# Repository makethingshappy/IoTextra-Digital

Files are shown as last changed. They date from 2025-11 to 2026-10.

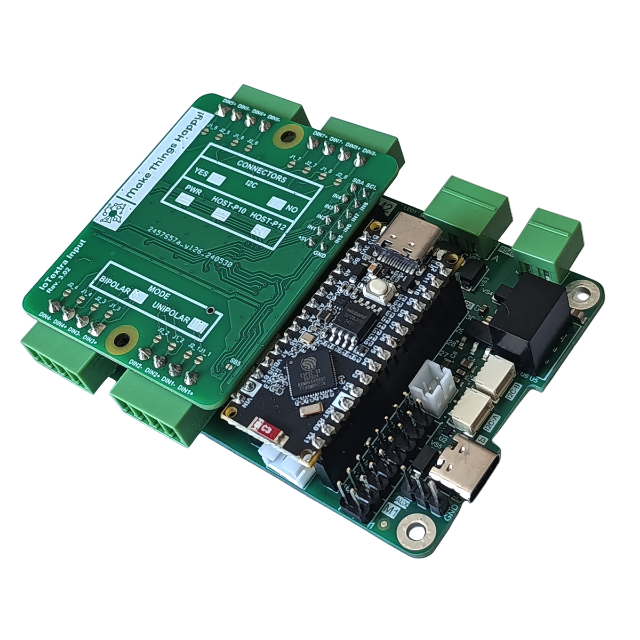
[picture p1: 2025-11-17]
Input/v.3.02/media/14_-_IoTbase_NANO_and_IoTextra_Input_with_ESP32-S3-Nano_Development_Board.png

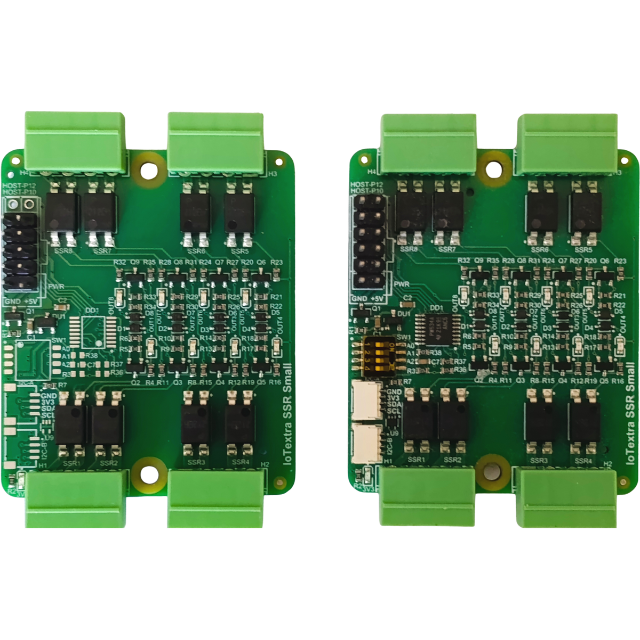
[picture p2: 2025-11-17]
SSR Small/v.3.02/media/02_-_IoTextra_SSR_Small_with_and_without_Qwiic_connector.png

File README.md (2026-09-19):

# IoTextra-Digital: Industrial Digital I/O Modules for MQTT & Node-RED Automation

## Overview

[**IoTextra-Digital**](https://makethingshappy.io/collections/digital-iotextra) is a family of isolated digital I/O modules designed for reliable operation in IoT, IIoT, and smart home environments.  
Each module combines digital inputs with relay, solid-state relay, transistor, or MOSFET outputs — the exact configuration, voltage range, and isolation technology vary by module and are documented in its own datasheet.

IoTextra modules integrate cleanly with IoTsmart MCU boards and can be used with MQTT and Node-RED workflows (e.g., via the IoTflow automation framework).

---

## Features & Capabilities

- Industrial-grade digital I/O, galvanically isolated per channel
- Relay, solid-state relay, transistor, or MOSFET outputs depending on the module
- Clean terminal block layout for fast, error-free wiring
- Compatible with IoTsmart modules, Raspberry Pi PICO, and other MCUs
- Suitable for long-term installations in smart buildings, labs, and light industrial systems

---

## Hardware Specifications

Each IoTextra-Digital module has its own electrical and mechanical specifications, documented inside its versioned folder.

Module folders:

- **[Input](./Input/)**
- **[MOSFET2](./MOSFET2/)**
- **[Octal](./Octal/)**
- **[Octal2](./Octal2/)**
- **[Octal3](./Octal3/)**
- **[Octal4](./Octal4/)**
- **[Relay](./Relay/)**
- **[Relay2](./Relay2/)**
- **[SSR Small](./SSR%20Small/)**

Typical documentation includes:

- Maximum input voltage and isolation rating (varies by module — see individual datasheet)
- Output type and ratings (relay, SSR, transistor, or MOSFET)
- Electrical thresholds and isolation design
- Load and protection characteristics
- Mechanical layout and terminal labeling

Refer to each module's documentation for exact technical data.

---

## Digital I/O Channel Configuration

Documentation includes:

- Input and output channel numbering
- Terminal block identification
- Wiring patterns for switches, sensors, and loads
- Recommended safety and polarity guidelines

> **Important:**  
> Output type differs by module — NPN transistor outputs (Octal2), MOSFET outputs (MOSFET2), and relay or solid-state relay outputs (all other modules). Check the specific module's datasheet before wiring.

---

## Wiring & Pinout Diagrams

Module-level wiring diagrams include:

- Terminal block layout  
- Polarity and signal direction  
- Relay/SSR/transistor/MOSFET load wiring examples  
- Safety considerations for higher-voltage operation  

See the diagrams located in each module's folder listed above.

---

## Software Support

IoTextra-Digital is a **hardware-only** series, but integrates cleanly into automation stacks.

Typical usage includes:

- Connecting module inputs/outputs to IoTsmart or Raspberry Pi PICO boards  
- Reading/writing digital I/O via GPIO or MCU firmware  
- Triggering MQTT events or Node-RED flows  
- Following IoTflow's MQTT topic conventions for automation

---

## Examples

IoTextra-Digital modules are used together with [**IoTsmart**](https://makethingshappy.io/collections/iotsmart) or [**IoTbase**](https://makethingshappy.io/collections/iotbase) boards and [**IoTflow-based**](https://makethingshappy.io/pages/iotflow) automation.

Module-specific diagrams and connection examples are included inside each module's folder listed above.

### MCU Firmware Examples (IoTsmart)

IoTsmart does **not** yet contain its own `/examples` folder.  
Firmware reference examples will be added in a future update.

### Node-RED Automation Examples (IoTflow)

👉 **IoTflow Node-RED Examples**  
https://github.com/makethingshappy/IoTflow/tree/main/Node-RED%20Examples

---

## Ordering Information

### 📦 SKU Information  
The complete list of SKUs is provided in the following PDF located in the repository root:

- **SKU Digital IoTextra.pdf**

---

### 🛒 Purchase Links  
Order directly from the official store:

* [**IoTextra Input Module**](https://makethingshappy.io/collections/digital-iotextra/products/iotextra-input)
* [**IoTextra MOSFET2 Module**](https://makethingshappy.io/collections/digital-iotextra/products/iotextra-mosfet2)
* [**IoTextra Octal Module**](https://makethingshappy.io/collections/digital-iotextra/products/iotextra-octal)
* [**IoTextra Octal2 Module**](https://makethingshappy.io/collections/digital-iotextra/products/iotextra-octal2)
* [**IoTextra Octal3 Module**](https://makethingshappy.io/collections/digital-iotextra/products/iotextra-octal3)
* [**IoTextra Octal4 Module**](https://makethingshappy.io/collections/digital-iotextra/products/iotextra-octal4)
* [**IoTextra Relay2 Module**](https://makethingshappy.io/collections/digital-iotextra/products/iotextra-relay2)
* [**IoTextra SSR Small Module**](https://makethingshappy.io/collections/digital-iotextra/products/iotextra-ssr-small)

---

## Licensing

This repository uses separate licenses for each category of assets:

- **Code:** [`LICENSE_CODE.md`](./LICENSE_CODE.md) — MIT License  
- **Schematics & Documentation:** [`LICENSE_HARDWARE.md`](./LICENSE_HARDWARE.md) — CC BY-SA 4.0  
- **Documentation:** [`LICENSE_DOCS.md`](./LICENSE_DOCS.md)  
- **Media:** [`LICENSE_MEDIA.md`](./LICENSE_MEDIA.md)

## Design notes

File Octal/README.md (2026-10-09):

<!-- OVERVIEW_START -->
> **IoTextra Octal**
>
> 4+2+2 I/O module · 4 digital inputs · 2 NPN outputs · 2 SPST relays · galvanic isolation · 3750 VRMS
>
> Inputs up to 36 VDC · outputs up to 100 VDC / 8 A · relay 250 VAC / 5 A · HOST and Qwiic connectors
>
> Works with Raspberry Pi, Raspberry Pi Pico / Pico 2 (RP2040 / RP2350) and ESP32
>
> DIN-rail mounting: A 3D-printable DIN-rail mounting tray is available — <a href="https://www.printables.com/model/1802141-din-rail-mount-for-make-things-happy-iotextra">view on Printables</a>
>
> Part of the IoTextra series · compatible with IoTsmart and IoTbase · Open Hardware
<!-- OVERVIEW_END -->

software

## SKU

See [SKU.md](SKU.md)

## Version history

| Version | Notes |
|---|---|
| 3.04 | QR code and logos added to bottom side |
| 3.03 | Initial GitHub release |

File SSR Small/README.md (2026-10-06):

<!-- OVERVIEW_START -->
> **IoTextra SSR Small**
>
> 8-channel solid-state relay module · SPST-NO · galvanic isolation · 5000 VRMS · on-resistance from 0.05 Ω
>
> GPIO and/or I²C modes · HOST and Qwiic connectors · 47×56 mm · 5 VDC supply
>
> Works with Raspberry Pi, Raspberry Pi Pico / Pico 2 (RP2040 / RP2350) and ESP32
>
> DIN-rail mounting: A 3D-printable DIN-rail mounting tray is available — <a href="https://www.printables.com/model/1802141-din-rail-mount-for-make-things-happy-iotextra">view on Printables</a>
>
> Part of the IoTextra series · compatible with IoTsmart and IoTbase · Open Hardware
<!-- OVERVIEW_END -->

software

## SKU

See [SKU.md](SKU.md)

## Version history

| Version | Notes |
|---|---|
| 3.02 | Initial GitHub release |

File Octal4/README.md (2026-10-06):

<!-- OVERVIEW_START -->
> **IoTextra Octal4**
>
> 4 isolated digital inputs · 4 SPST relays · galvanic isolation · 2500 VRMS
>
> Inputs field-configurable 12/18/24/36 VDC per channel via solder jumpers · relay contacts 250 VAC / 30 VDC / 5 A · control via GPIO and/or I²C (TCA9534)
>
> Works with Raspberry Pi, Raspberry Pi Pico / Pico 2 (RP2040 / RP2350) and ESP32
>
> DIN-rail mounting: A 3D-printable DIN-rail mounting tray is available — <a href="https://www.printables.com/model/1802141-din-rail-mount-for-make-things-happy-iotextra">view on Printables</a>
>
> Part of the IoTextra series · compatible with IoTsmart and IoTbase · Open Hardware
<!-- OVERVIEW_END -->

software

## SKU

See [SKU.md](SKU.md)

## Version history

| Version | Notes |
|---|---|
| 3.02 | Initial GitHub release |

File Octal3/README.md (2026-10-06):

<!-- OVERVIEW_START -->
> **IoTextra Octal3**
>
> 4 isolated digital inputs · 4 latching DPDT relays · galvanic isolation · 3750 VRMS
>
> Inputs up to 36 VDC via GPIO · relay contacts 250 VAC / 220 VDC / 2 A · relay control via I²C → TCA9534A → DRV8837C
>
> Works with Raspberry Pi, Raspberry Pi Pico / Pico 2 (RP2040 / RP2350) and ESP32
>
> DIN-rail mounting: A 3D-printable DIN-rail mounting tray is available — <a href="https://www.printables.com/model/1802141-din-rail-mount-for-make-things-happy-iotextra">view on Printables</a>
>
> Part of the IoTextra series · compatible with IoTsmart and IoTbase · Open Hardware
<!-- OVERVIEW_END -->

software

latching

## SKU

See [SKU.md](SKU.md)

## Version history

| Version | Notes |
|---|---|
| 3.02 | Initial GitHub release |

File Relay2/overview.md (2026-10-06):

# IoTextra Relay2

4-channel SPDT relay module · 250 VAC / 30 VDC · 10 A · GPIO and/or I²C modes

Relay options: Panasonic ALQ105 · Omron G5Q-14 · HF33F/005-ZS3 · TE PE014005 · HOST and Qwiic connectors

Works with Raspberry Pi, Raspberry Pi Pico / Pico 2 (RP2040 / RP2350) and ESP32

DIN-rail mounting: A 3D-printable DIN-rail mounting tray is available — <a href="https://www.printables.com/model/1802141-din-rail-mount-for-make-things-happy-iotextra">view on Printables</a>

Part of the IoTextra series · compatible with IoTsmart and IoTbase · Open Hardware

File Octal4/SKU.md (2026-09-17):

# SKU — IoTextra Octal4

```
040305vvvrcc
```

| Field | Description |
|---|---|
| `040305` | Product code — IoTextra Octal4 |
| `vvv` | Version (e.g. 302 = version 3.02) |
| `r` | Relay model |
| `cc` | Communication |

**Relay model (r):**

| Value | Description |
|---|---|
| 1 | HF49FD |
| 2 | APAN3105 |

**Communication (cc):**

| Value | Description |
|---|---|
| 11 | HOST-12 connector and two I²C connectors |

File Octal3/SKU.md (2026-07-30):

# SKU — IoTextra Octal3

```
040304vvvrcc
```

| Field | Description |
|---|---|
| `040304` | Product code — IoTextra Octal3 |
| `vvv` | Version (e.g. 302 = version 3.02) |
| `r` | Relay model |
| `cc` | Communication |

**Relay model (r):**

| Value | Description |
|---|---|
| 3 | KEMET EC2-5SNU |

**Communication (cc):**

| Value | Description |
|---|---|
| 09 | HOST-12 connector |
| 11 | HOST-12 connector and two I²C connectors |

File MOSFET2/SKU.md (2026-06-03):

# SKU — IoTextra MOSFET2

```
040206vvvmpc
```

| Field | Description |
|---|---|
| `040206` | Product code — IoTextra MOSFET2 |
| `vvv` | Version (e.g. 302 = version 3.02) |
| `m` | MOSFET variant (load voltage / load current) |
| `p` | DC-DC converter |
| `c` | Communication |

**MOSFET variant (m):**

| Value | Description |
|---|---|
| 1 | 30 VDC / 9 A |
| 2 | 60 VDC / 7 A |
| 3 | 90 VDC / 6 A |

**DC-DC converter (p):**

| Value | Description |
|---|---|
| 1 | 5V→5V |
| 2 | 5V→5V tall |
| 3 | 2× (5V→5V tall) |
| 4 | 5V→12V tall |

**Communication (c):**

| Value | Description |
|---|---|
| A | HOST-10 connector |
| 9 | HOST-12 connector |
| B | HOST-12 connector and two I²C connectors |

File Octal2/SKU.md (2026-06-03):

# SKU — IoTextra Octal2

```
040303vvvscc
```

| Field | Description |
|---|---|
| `040303` | Product code — IoTextra Octal2 |
| `vvv` | Version (e.g. 302 = version 3.02) |
| `s` | Signal type |
| `cc` | Communication |

**Signal type (s):**

| Value | Description |
|---|---|
| 2 | Bipolar |
| 3 | Extended |

**Communication (cc):**

| Value | Description |
|---|---|
| 10 | HOST-10 connector |
| 09 | HOST-12 connector |
| 11 | HOST-12 connector and two I²C connectors |

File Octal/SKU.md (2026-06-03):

# SKU — IoTextra Octal

```
040302vvvrcc
```

| Field | Description |
|---|---|
| `040302` | Product code — IoTextra Octal |
| `vvv` | Version (e.g. 304 = version 3.04) |
| `r` | Relay model |
| `cc` | Communication |

**Relay model (r):**

| Value | Description |
|---|---|
| 1 | HF49FD |
| 2 | APAN3105 |

**Communication (cc):**

| Value | Description |
|---|---|
| 10 | HOST-10 connector |
| 11 | HOST-12 connector and two I²C connectors |

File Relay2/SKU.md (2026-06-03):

# SKU — IoTextra Relay2

```
040202vvvrcc
```

| Field | Description |
|---|---|
| `040202` | Product code — IoTextra Relay2 |
| `vvv` | Version (e.g. 302 = version 3.02) |
| `r` | Relay model |
| `cc` | Communication |

**Relay model (r):**

| Value | Description |
|---|---|
| 1 | HF33F/005-ZS3 |
| 2 | Panasonic ALQ105 |
| 3 | Omron G5Q-14 |
| 4 | TE PE014005 |

**Communication (cc):**

| Value | Description |
|---|---|
| 10 | HOST-10 connector |
| 11 | HOST-12 connector and two I²C connectors |

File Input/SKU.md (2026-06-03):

# SKU — IoTextra Input

```
040101vvvscc
```

| Field | Description |
|---|---|
| `040101` | Product code — IoTextra Input |
| `vvv` | Version (e.g. 302 = version 3.02) |
| `s` | Signal type |
| `cc` | Communication |

**Signal type (s):**

| Value | Description |
|---|---|
| 0 | Unipolar |
| 1 | Bipolar |

**Communication (cc):**

| Value | Description |
|---|---|
| 10 | HOST-10 connector |
| 09 | HOST-12 connector |
| 11 | HOST-12 connector and two I²C connectors |

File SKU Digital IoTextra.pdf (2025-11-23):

## SKU - Digital IoTextra

IoTextra Input
040101vvvscc
vvv | - | Version (for example, 302 is version 3.02)
s | - | Signal type (0 – Unipolar, 1 – Bipolar)
сс | - | Communication:
| | 10 –HOST-10 connector
| | 02 – PWR connector and two I²C connectors
| | 09 – HOST-12 connector
| | 11– HOST-12 connector and two I2C connectors

IoTextra Relay2
040202vvvrcc
vvv | - | Version (for example, 302 is version 3.02)
r | - | Relay model:
| | 1 – 33F/005
| | 2 – ALQ105
| | 3 – G5Q-14
| | 4 – PE014005
сс | - | Communication:
| | 10 –HOST-10 connector
| | 02 – PWR connector and two I²C connectors
| | 11– HOST-12 connector and two I2C connectors

IoTextra SSR Small
040203vvvlcc
vvv | - | Version (for example, 302 is version 3.02)
l | - | Load voltage / Load current:
| | 1 – 350VAC / 0.12A
| | 2 – 60VDC / 0.5A
| | 3 – 40VDC / 2A
| | 4 – 30VDC / 4A
сс | - | Communication:
| | 10 –HOST-10 connector
| | 02 – PWR connector and two I²C connectors
| | 09 – HOST-12 connector
| | 11– HOST-12 connector and two I2C connectors

IoTextra Octal2
040101vvvscc
vvv | - | Version (for example, 302 is version 3.02)
s | - | Signal type (1 – Unipolar, 2 – Bipolar, 3 – Extended)
сс | - | Communica:
| | 10 –HOST-10 connector
| | 02 – PWR connector and two I²C connectors
| | 09 – HOST-12 connector
| | 11– HOST-12 connector and two I2C connectors

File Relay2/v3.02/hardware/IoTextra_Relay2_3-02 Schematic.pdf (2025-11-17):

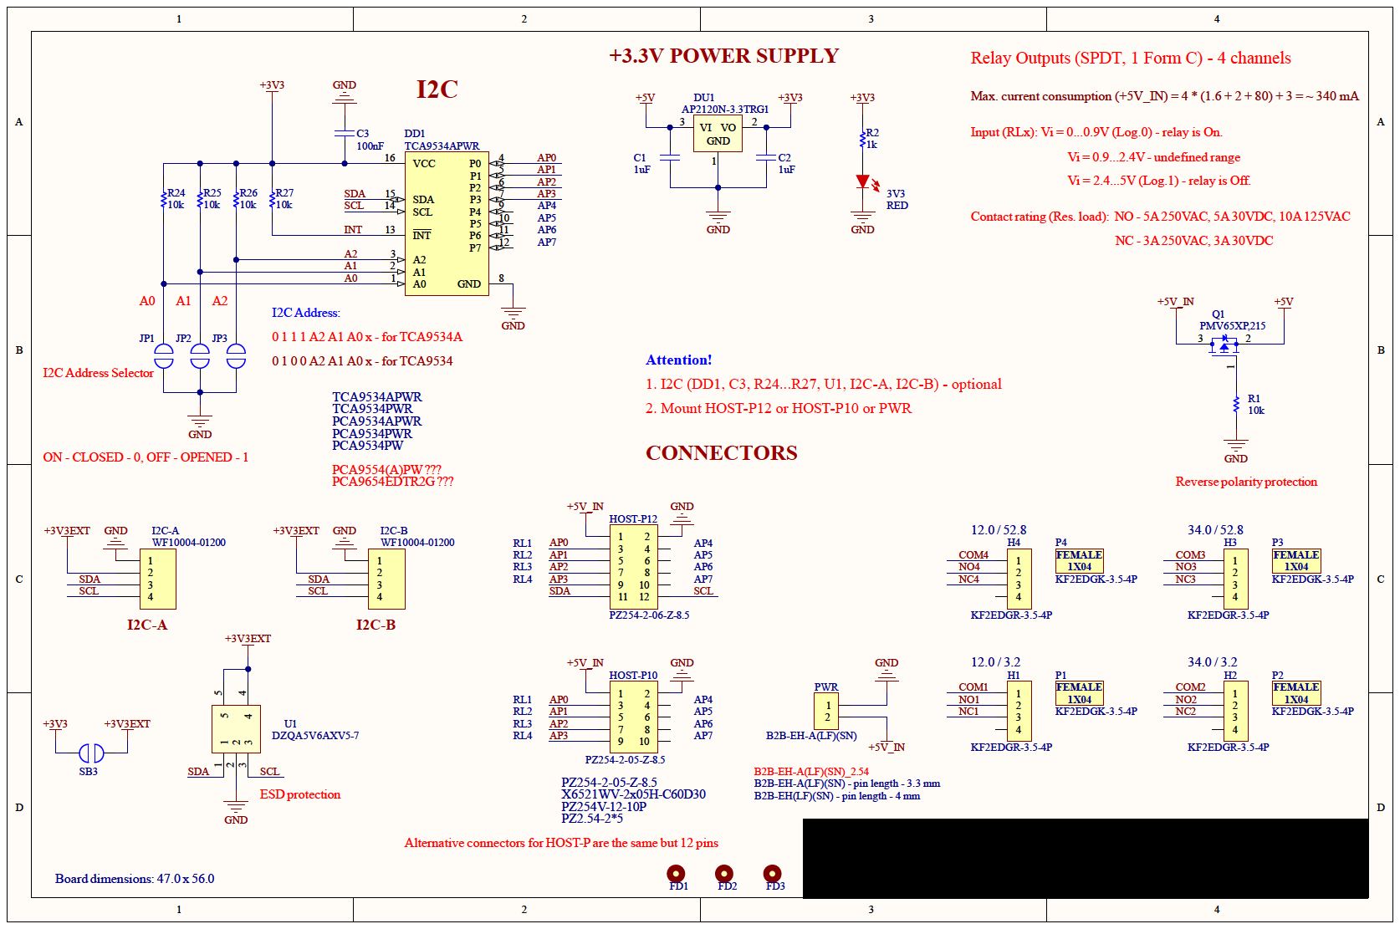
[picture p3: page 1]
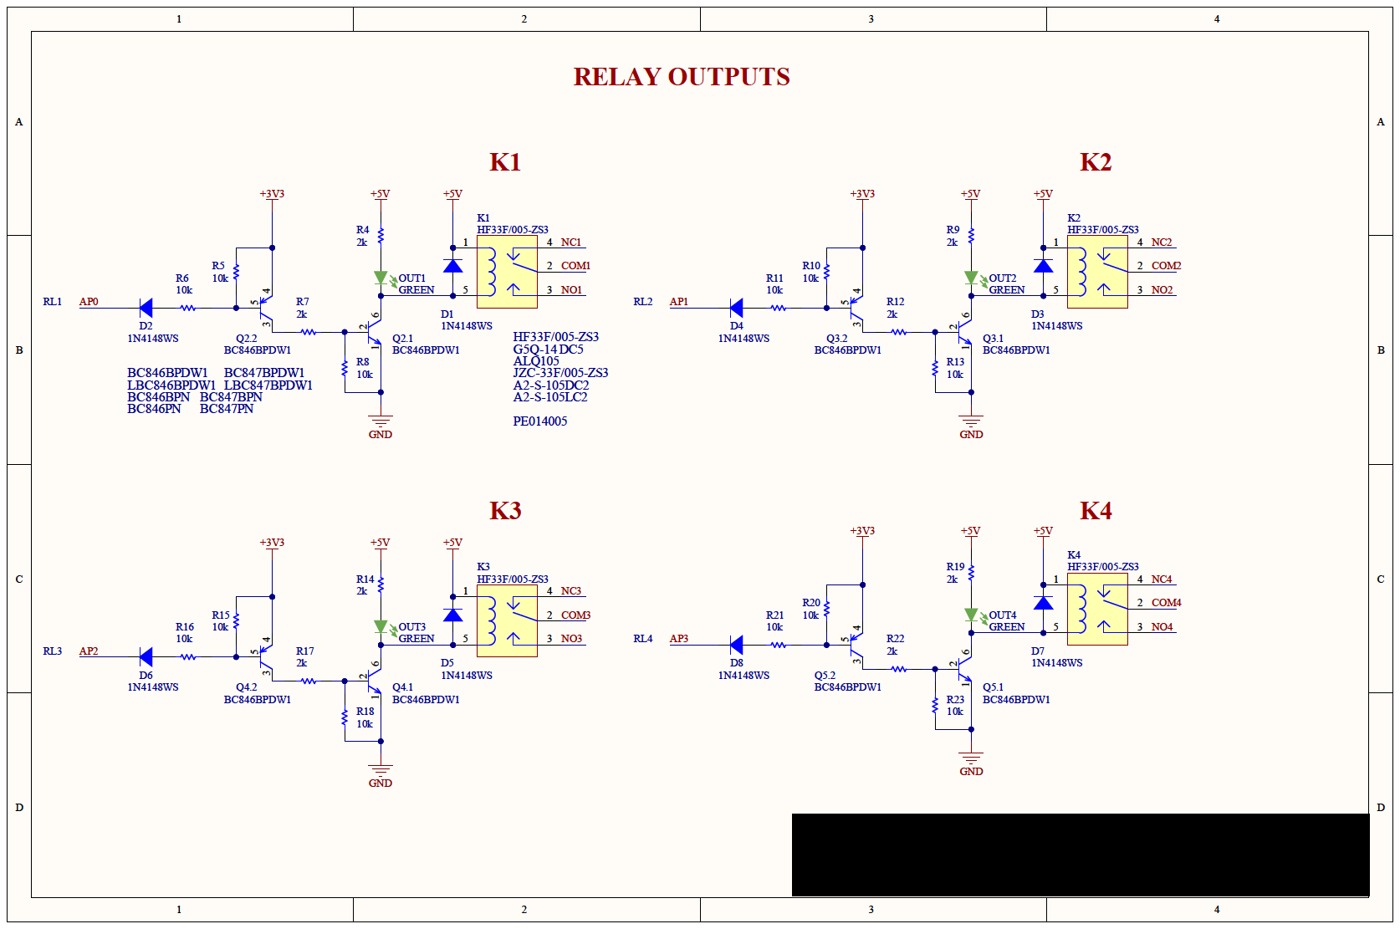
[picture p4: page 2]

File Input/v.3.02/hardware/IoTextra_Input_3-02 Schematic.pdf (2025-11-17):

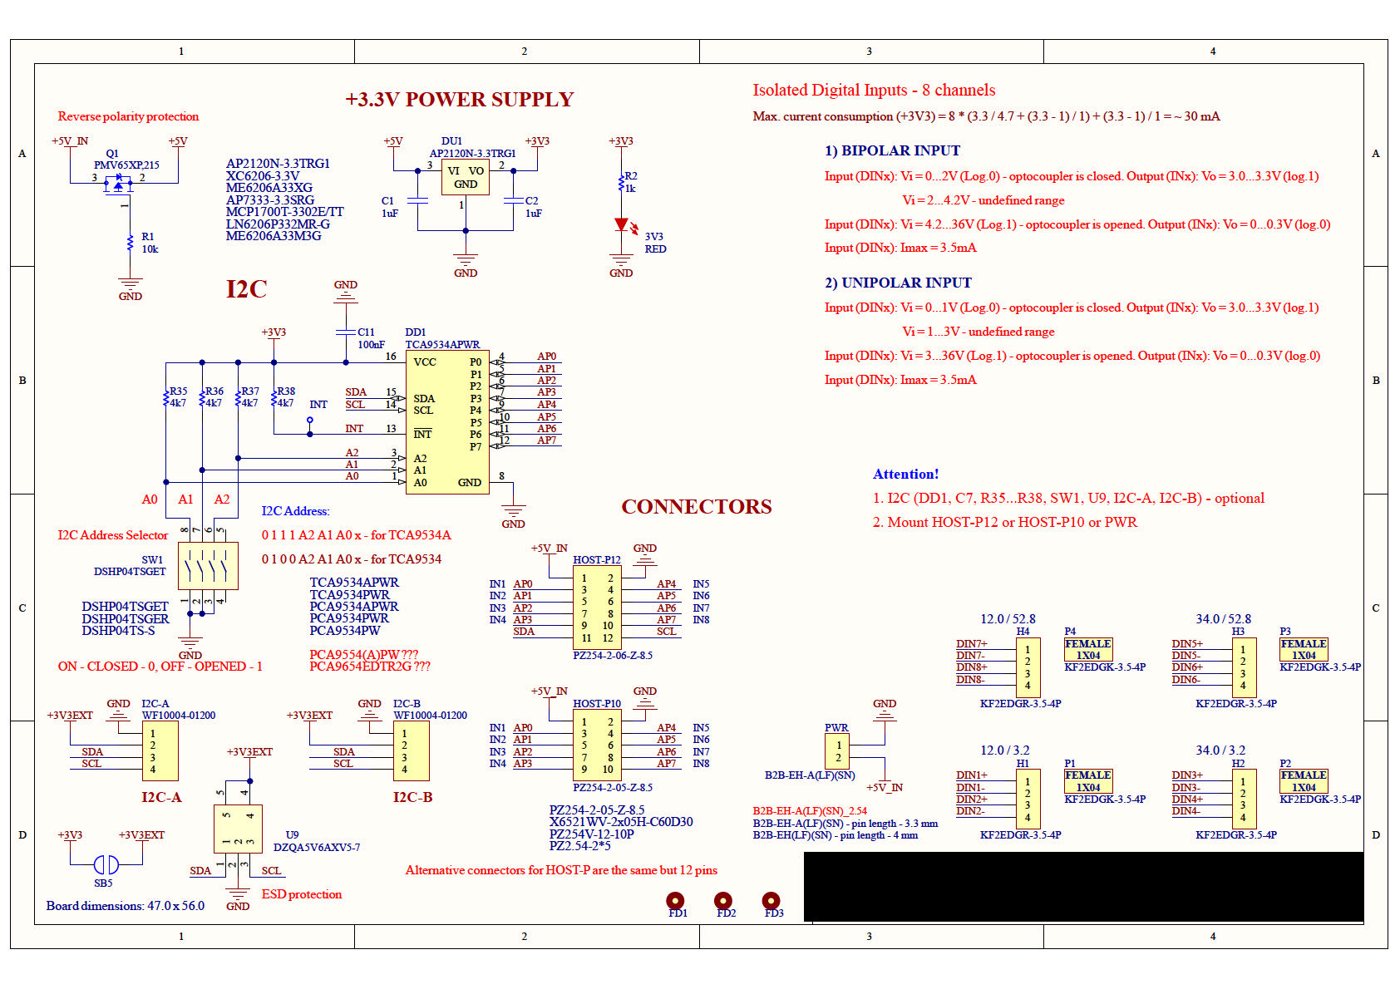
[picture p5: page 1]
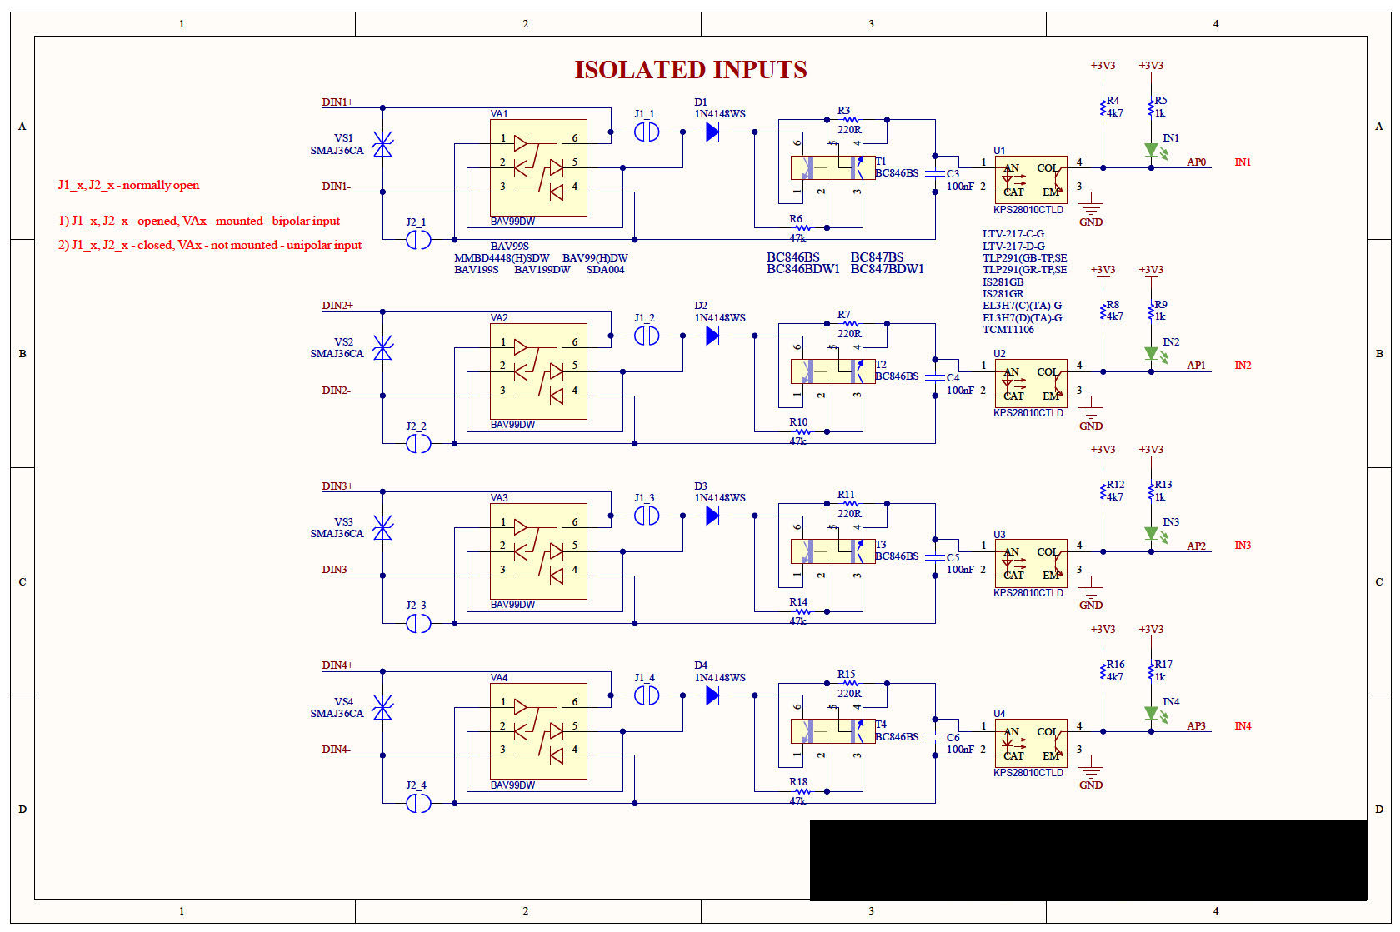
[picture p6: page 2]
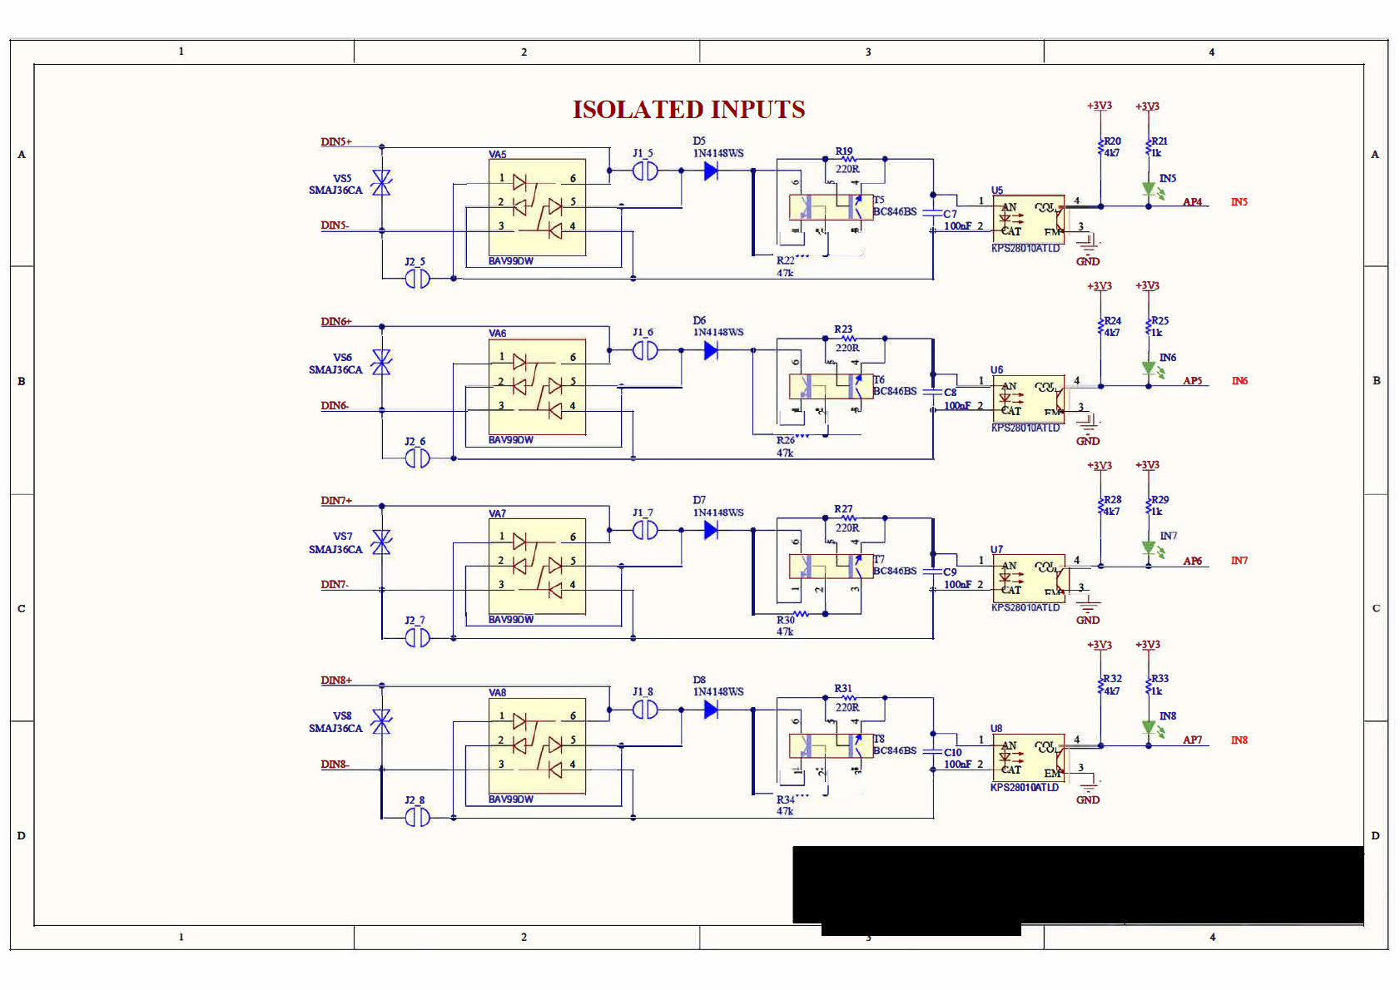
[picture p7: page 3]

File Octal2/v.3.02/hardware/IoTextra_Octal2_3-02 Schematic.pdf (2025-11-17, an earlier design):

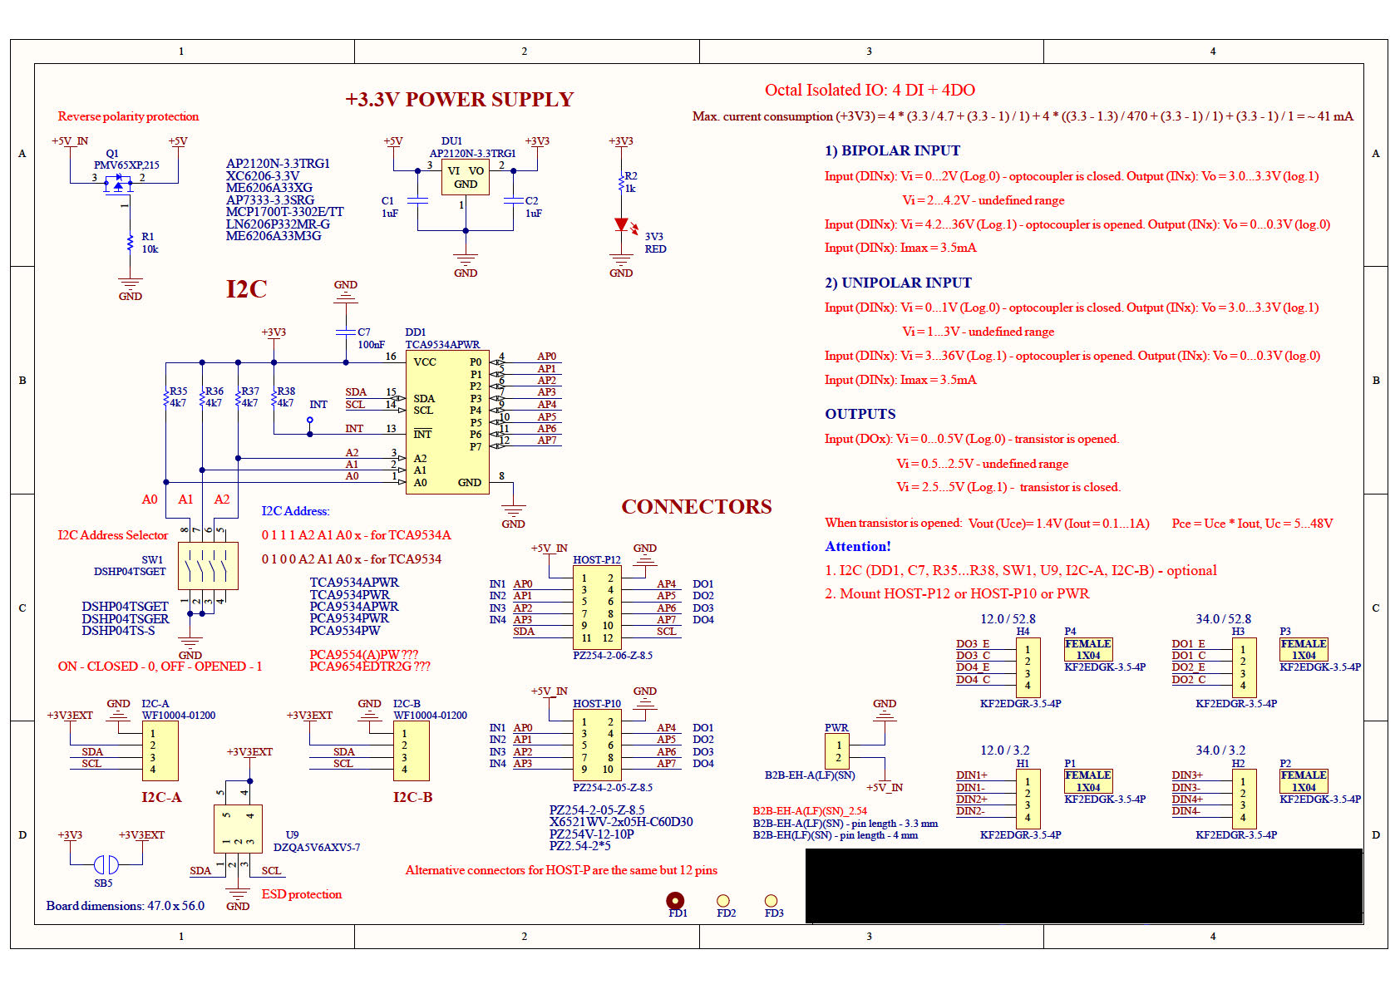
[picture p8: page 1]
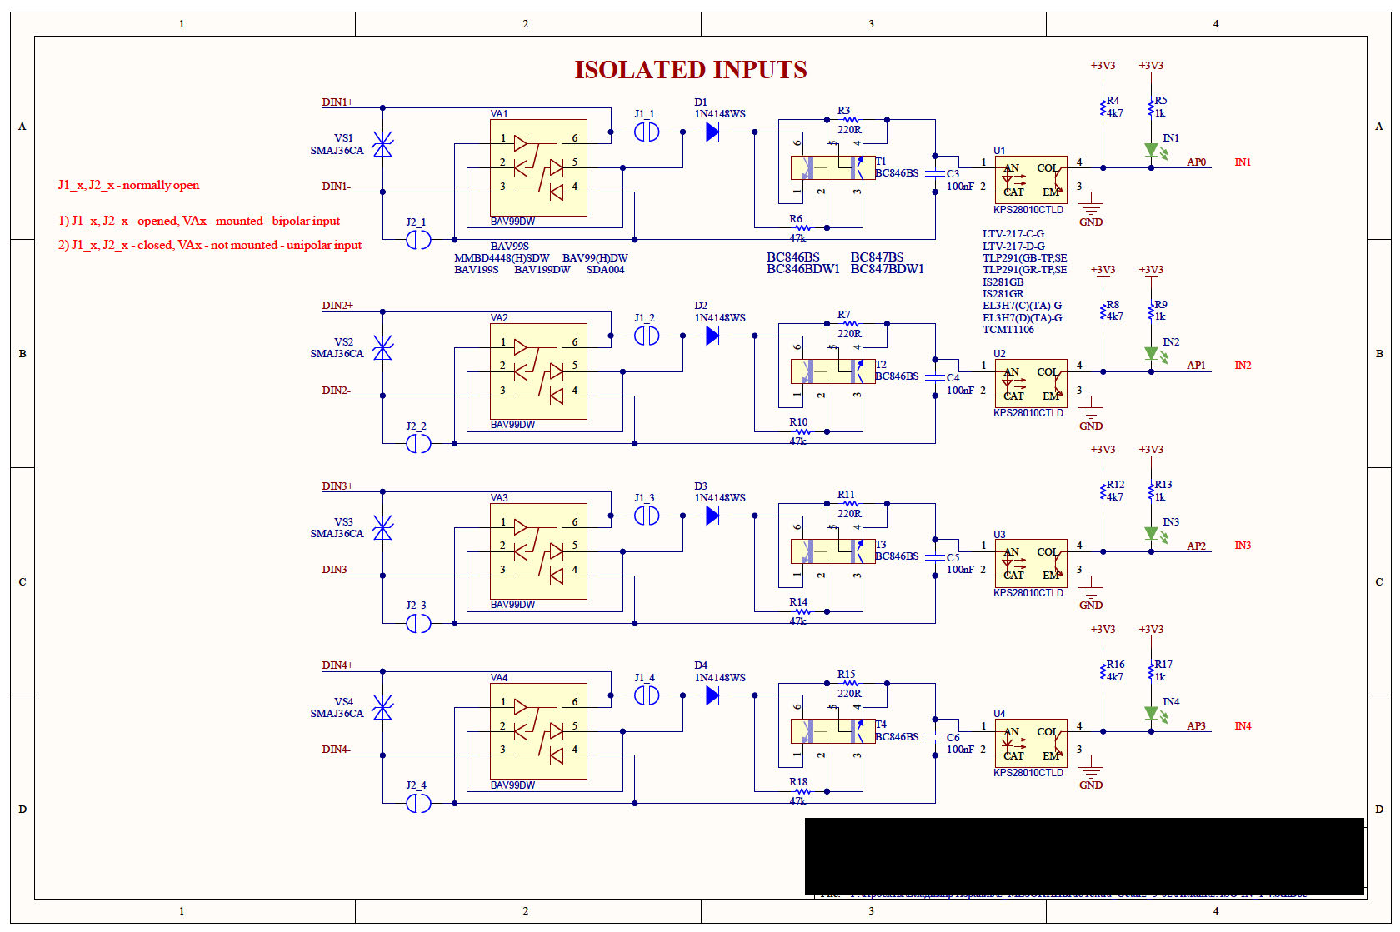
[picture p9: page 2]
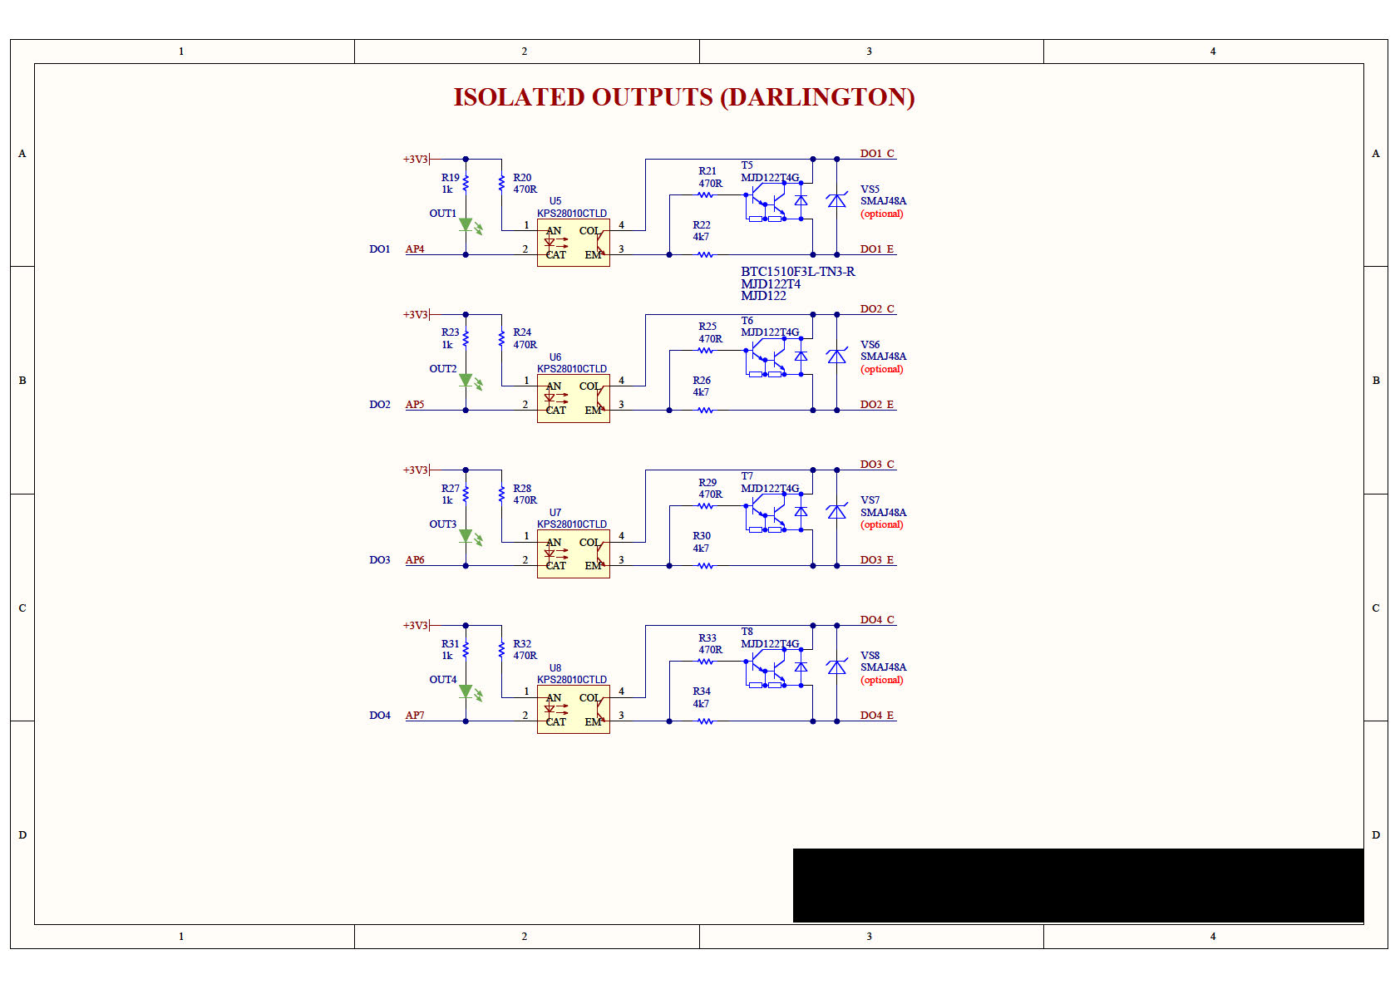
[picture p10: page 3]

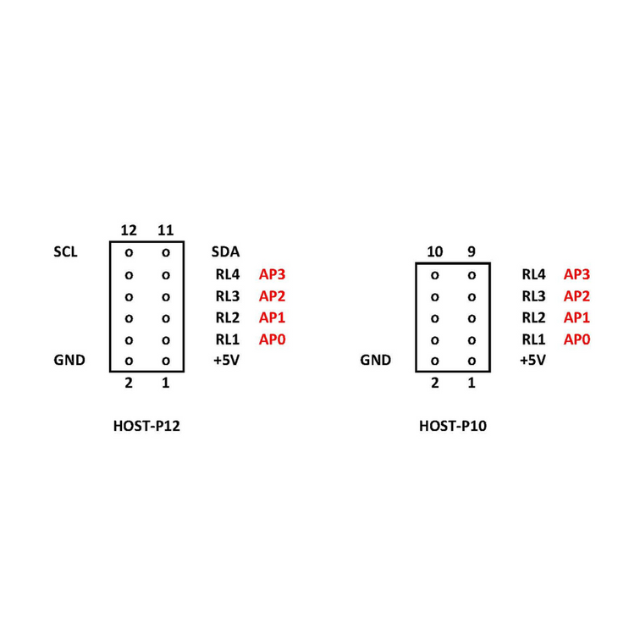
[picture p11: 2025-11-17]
Relay2/v3.02/media/05_-_IoTextra_Relay2_HOST_connector_pinout.png

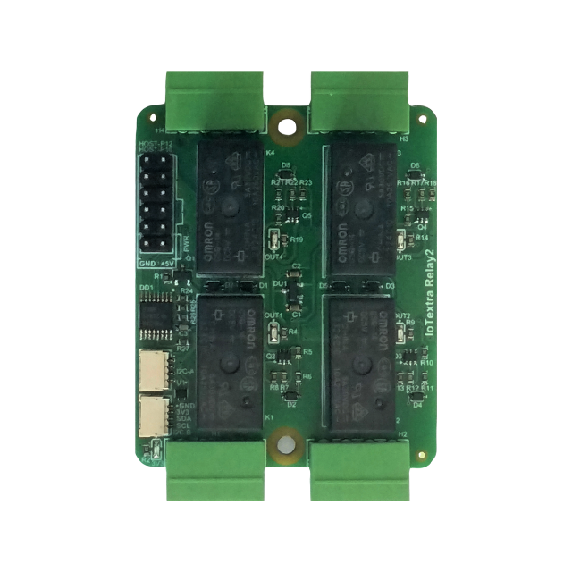
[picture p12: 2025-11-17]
Relay2/v3.02/media/03_-_IoTextra_Relay2_TOP_view.png

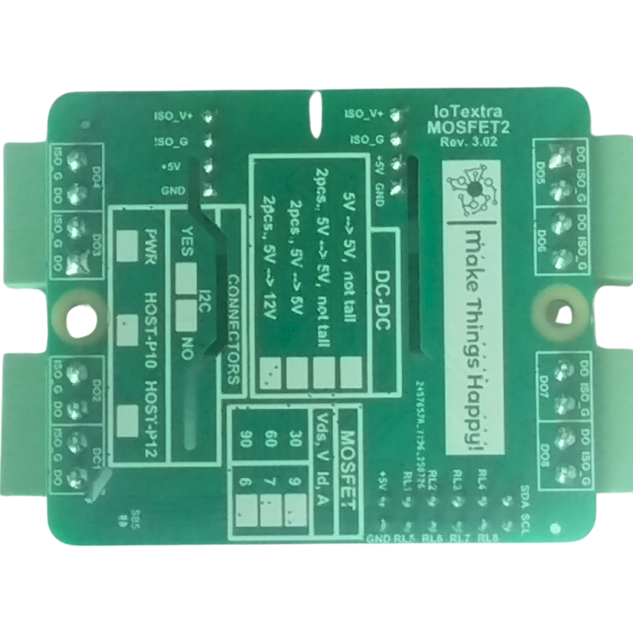
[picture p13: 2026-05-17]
MOSFET2/v.3.02/media/03 - IoTextra MOSFET2 BOTTOM view.png

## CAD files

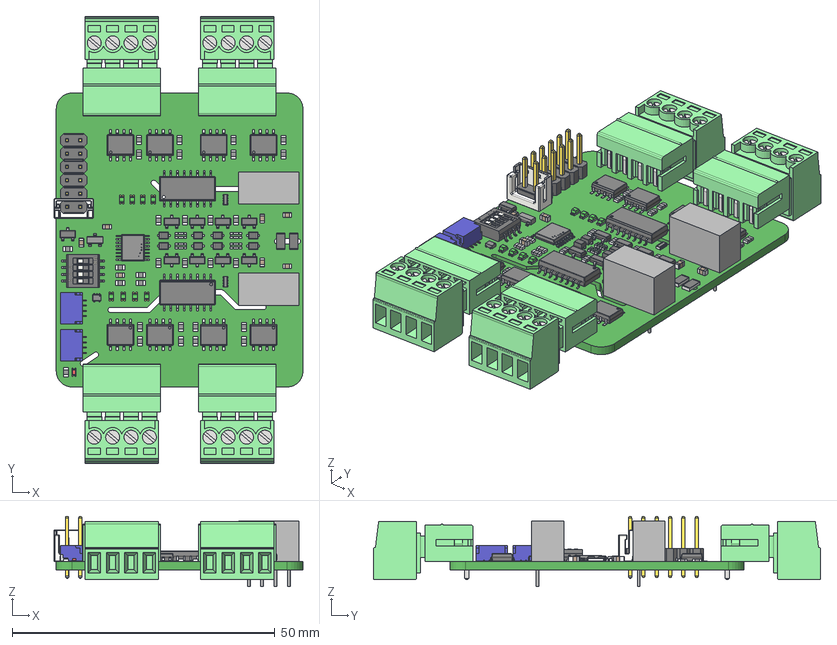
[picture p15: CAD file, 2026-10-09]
MOSFET2/v.3.02/hardware/IoTextra MOSFET2 ver.3-02.step
47.4 x 85.2 x 13.4 mm
Resistor_Array_YC_AF_xxx_YC124-FR-0759RL x 2
EXB28V_PAN x 4
NZQA5V6XV5T1G
Mid Body x 2
Mark x 2
CRE1_3C_MUR_RGB8421504 x 2
RESC1608X50N x 30
Leader x 123
CAPC1608X100N x 7
Lens x 8
User Library-SOD323F-1 x 8
PLD-12
B2B-EH-A
JST Logo adjustable
SMT_switch_04
BODY-TSSOP
LEAD-TSSOP x 16
Texas Logo Yury
Texas Logo Yury - Copy
SM04B-SRSS-TB x 2
PLD-10
ECH350R-04P x 4
EC350V-04P x 4
SOT95P240X110-3N

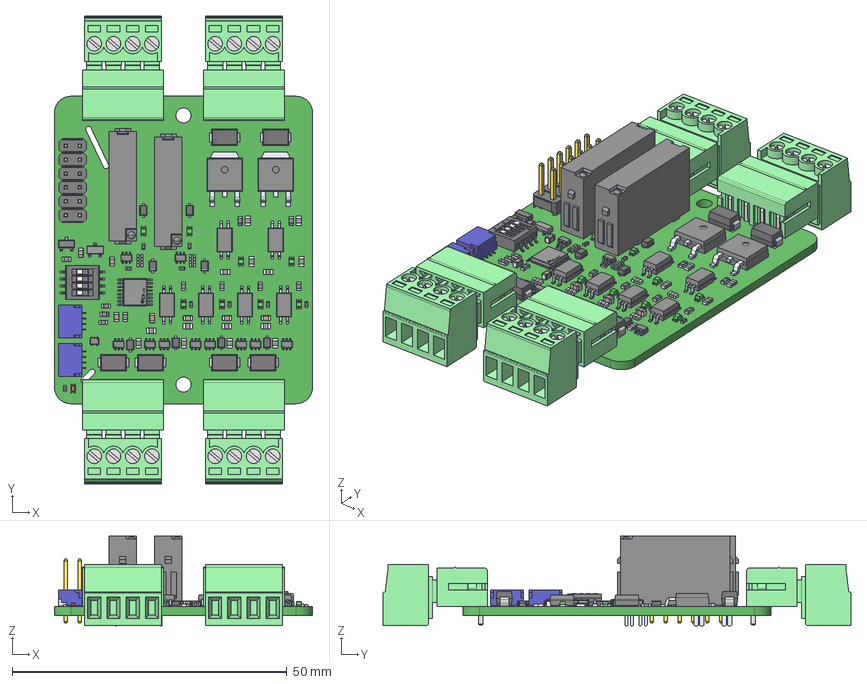
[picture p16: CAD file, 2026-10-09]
Octal/v.3.04/hardware/IoTextra Octal 3-04.step
47.0 x 85.2 x 16.3 mm
TCMD1000--3DModel-STEP-56544 x 6
User Library-S1G-1 x 6
RESC1608X50N x 14
Lens x 8
Mid Body x 9
Mark x 9
User Library-SOD323F-1 x 8
PLD-12
NZQA5V6XV5T1G
Leader x 3
SMT_switch_04
CAPC1608X100N x 7
BODY-TSSOP
LEAD-TSSOP x 16
Texas Logo Yury
Texas Logo Yury - Copy
SM04B-SRSS-TB x 2
PLD-10
ECH350R-04P x 4
EC350V-04P x 4
SOT95P240X110-3N
Extruded x 4
EXB28V_PAN x 2

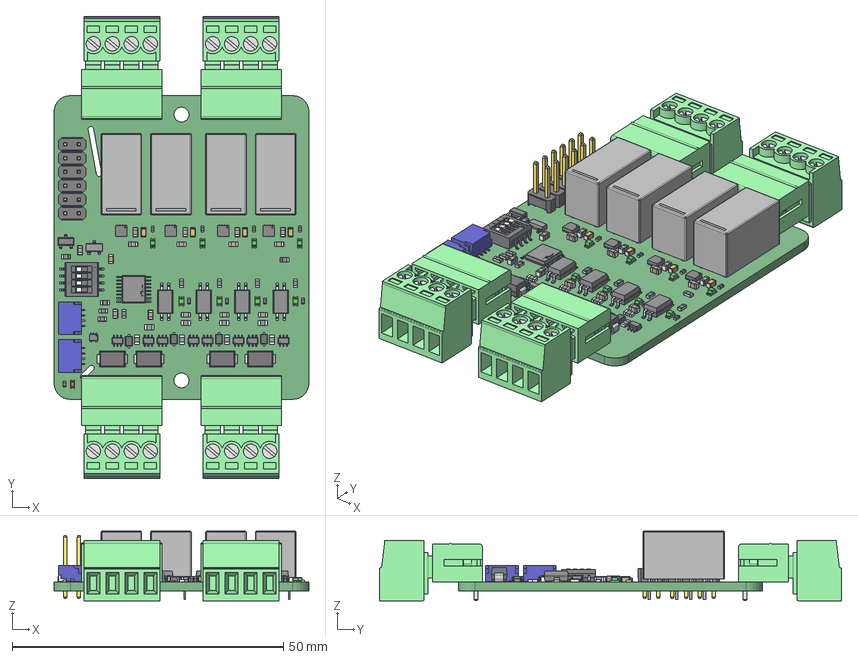
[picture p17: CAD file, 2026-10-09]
Octal3/v.3.02/hardware/IoTextra Octal3 3-02.step
47.0 x 85.2 x 12.8 mm
Thermal Shape x 4
Lens x 8
EC2-5SNU--3DModel-STEP-269445_RGB8421504 x 4
CAPC1608X100N x 15
Mid Body x 9
Mark x 9
PLD-12
NZQA5V6XV5T1G
Leader x 3
SMT_switch_04
BODY-TSSOP
LEAD-TSSOP x 16
Texas Logo Yury
Texas Logo Yury - Copy
SM04B-SRSS-TB x 2
RESC1608X50N x 8
TCMD1000--3DModel-STEP-56544 x 4
ECH350R-04P x 4
EC350V-04P x 4
SOT95P240X110-3N
User Library-SOD323F-1 x 4
User Library-S1G-1 x 4
Extruded x 4

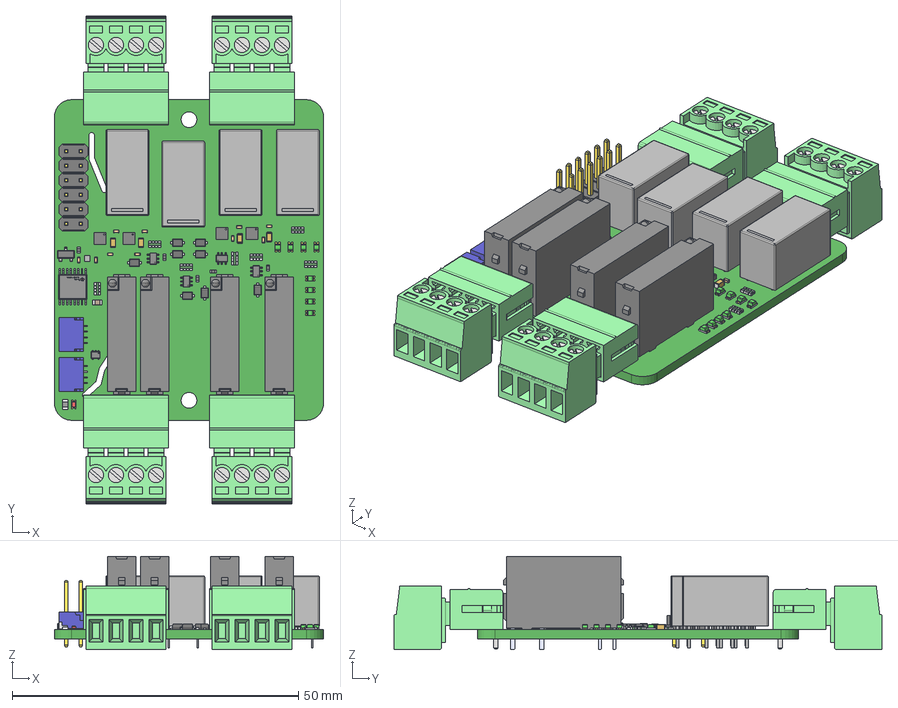
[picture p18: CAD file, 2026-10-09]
Relay/v.3.02/hardware/IoTextra Relay 3-02.step
47.0 x 85.2 x 16.3 mm
Extruded
EXB28V_PAN x 7
Thermal Shape x 4
EC2-5SNU--3DModel-STEP-269445_RGB8421504 x 4
Lens x 8
ceramic_cap_0402 x 10
PLD-12
NZQA5V6XV5T1G
Mid Body x 5
Mark x 5
Leader x 3
SM04B-SRSS-TB x 2
BODY-TSSOP
LEAD-TSSOP x 16
Texas Logo Yury
Texas Logo Yury - Copy
CAPC1608X100N
RESC1608X50N
ECH350R-04P x 4
EC350V-04P x 4
User Library-SOD323F-1 x 8

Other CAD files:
Octal4/v.3.02/hardware/IoTextra Octal4 3-02.step

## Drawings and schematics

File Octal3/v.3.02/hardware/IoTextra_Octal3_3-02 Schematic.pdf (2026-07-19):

# +3.3V POWER SUPPL

Y

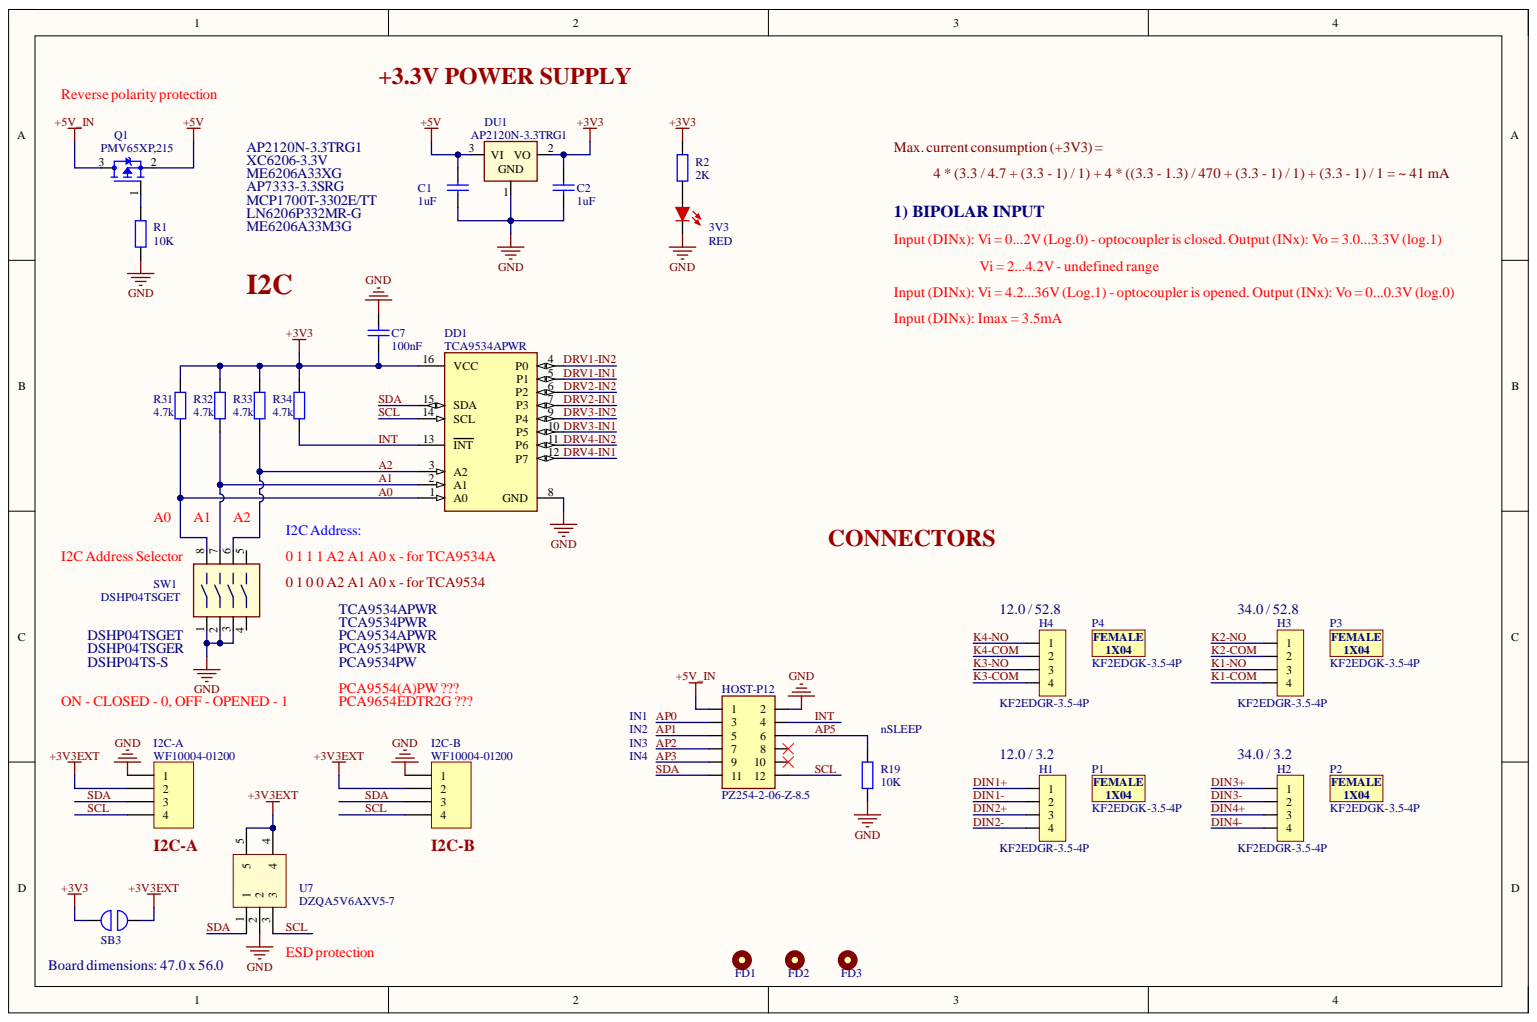
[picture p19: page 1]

# ISOLATED INPUTS

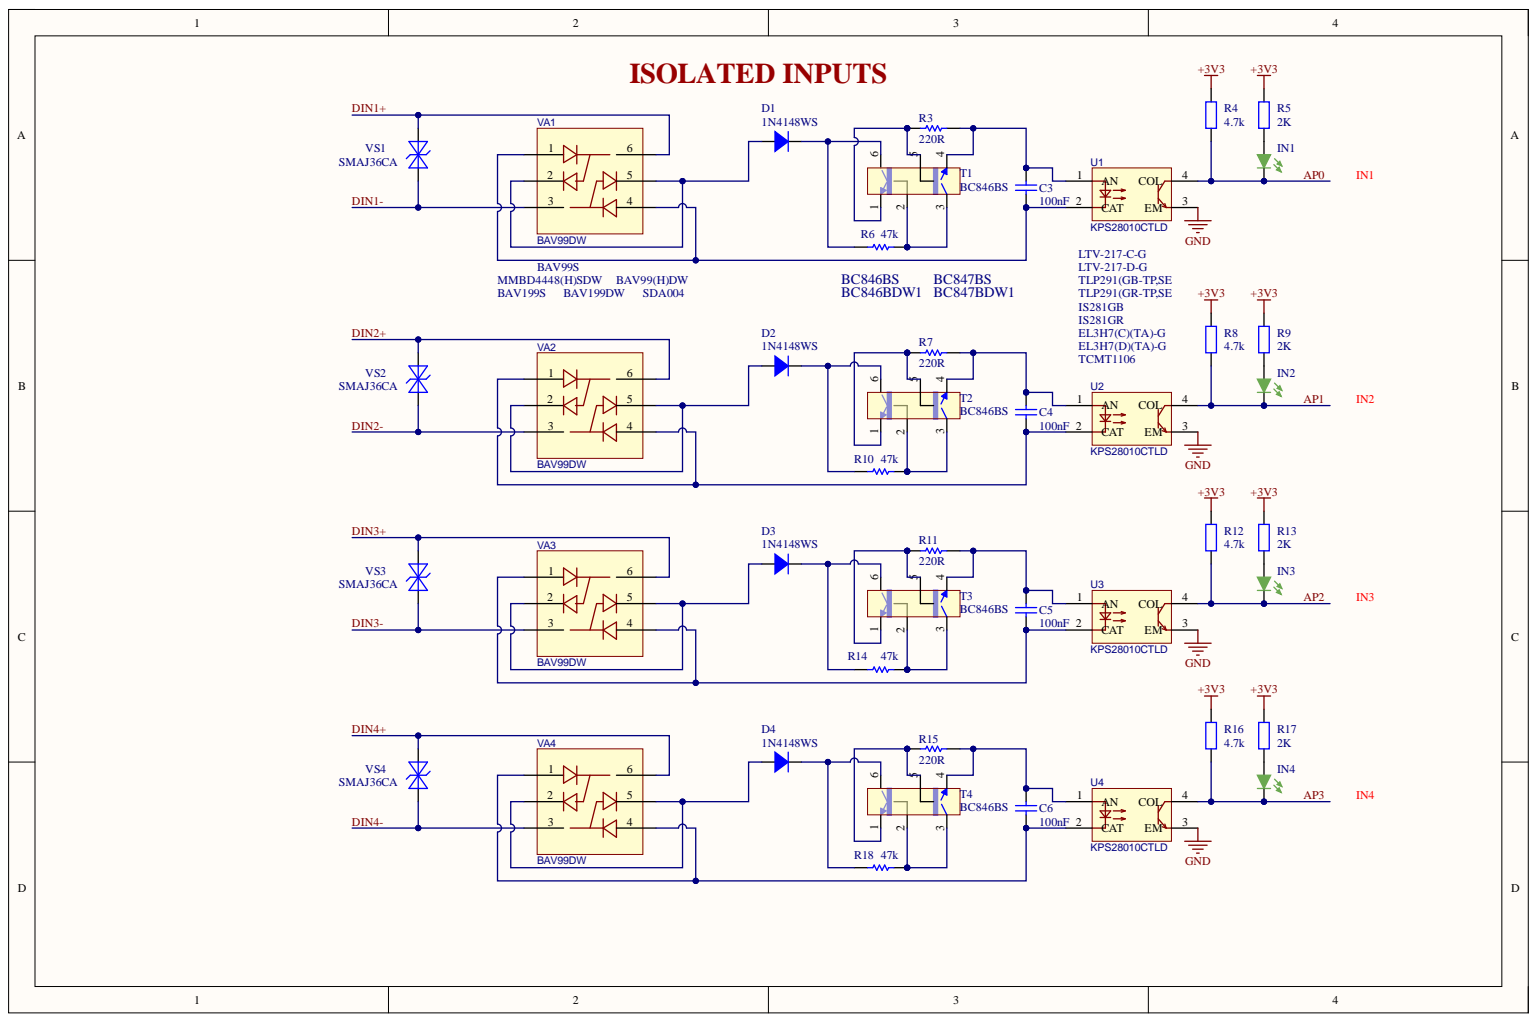
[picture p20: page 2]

# RELA

# Y OUTPUTS

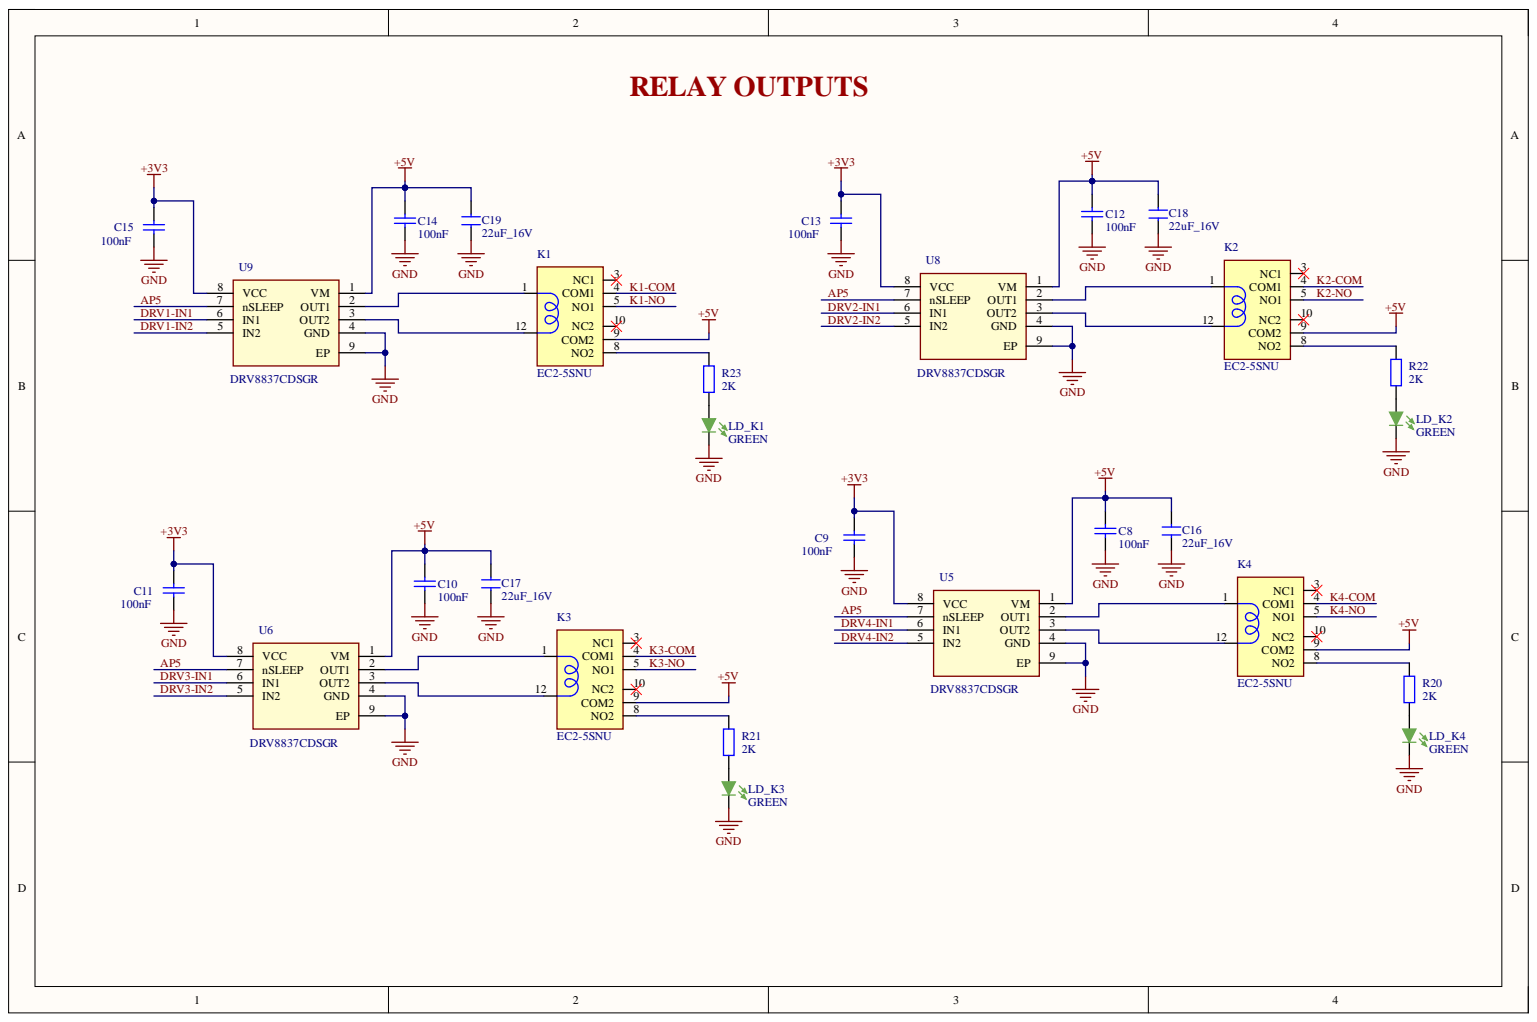
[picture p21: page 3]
nSL; VCC; KLD; GRE; K4 GRE

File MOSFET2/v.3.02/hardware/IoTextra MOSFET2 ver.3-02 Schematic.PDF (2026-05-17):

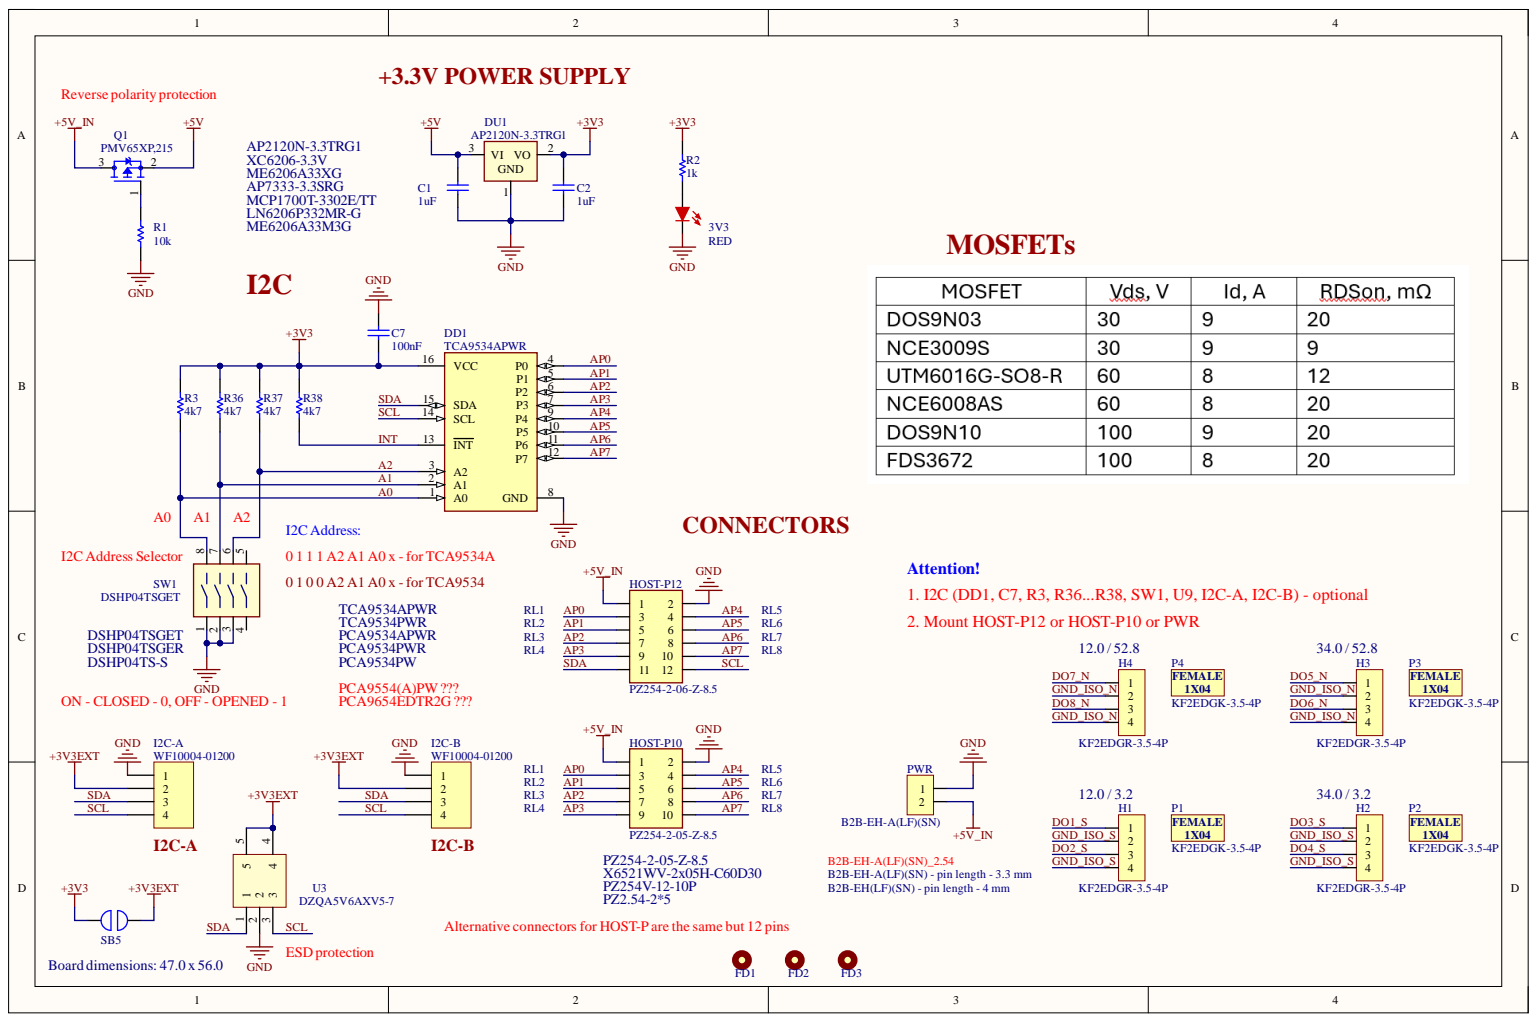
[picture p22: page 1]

2. Mount HOST-P12 or HOST-P10 or PWR

ON - CLOSED - 0, OFF - OPENED - 1

B2B-EH-A(LF)(SN) - pin length - 3.3 mm
B2B-EH(LF)(SN) - pin length - 4 mm

Alternative connectors for HOST-P are the same but 12 pins

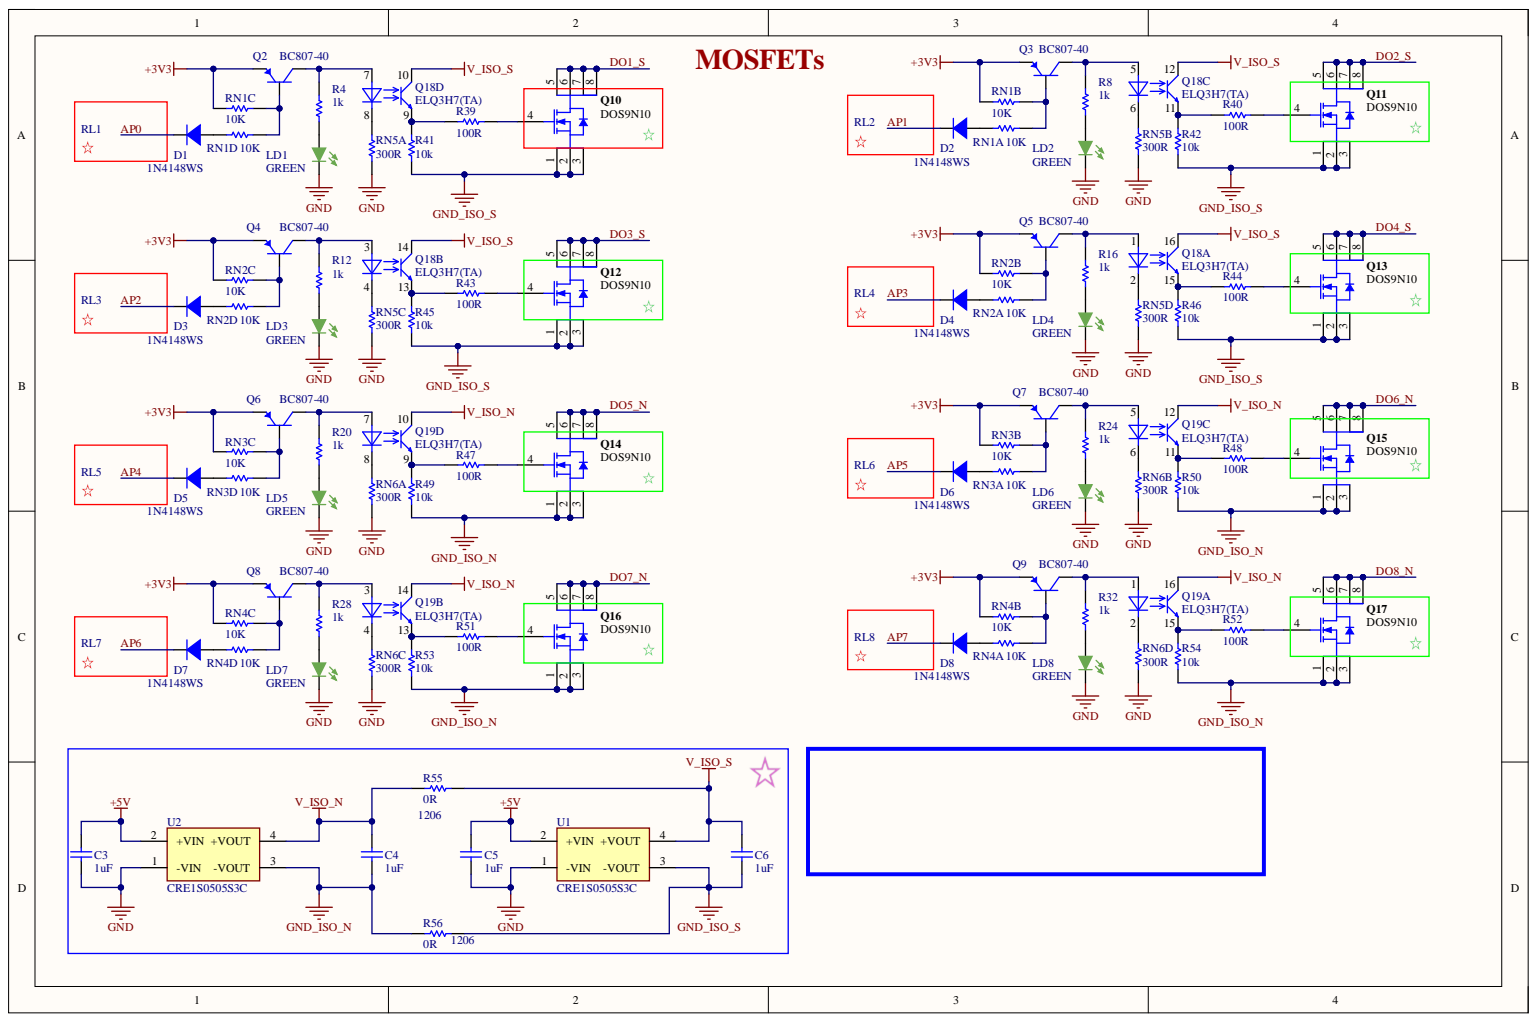
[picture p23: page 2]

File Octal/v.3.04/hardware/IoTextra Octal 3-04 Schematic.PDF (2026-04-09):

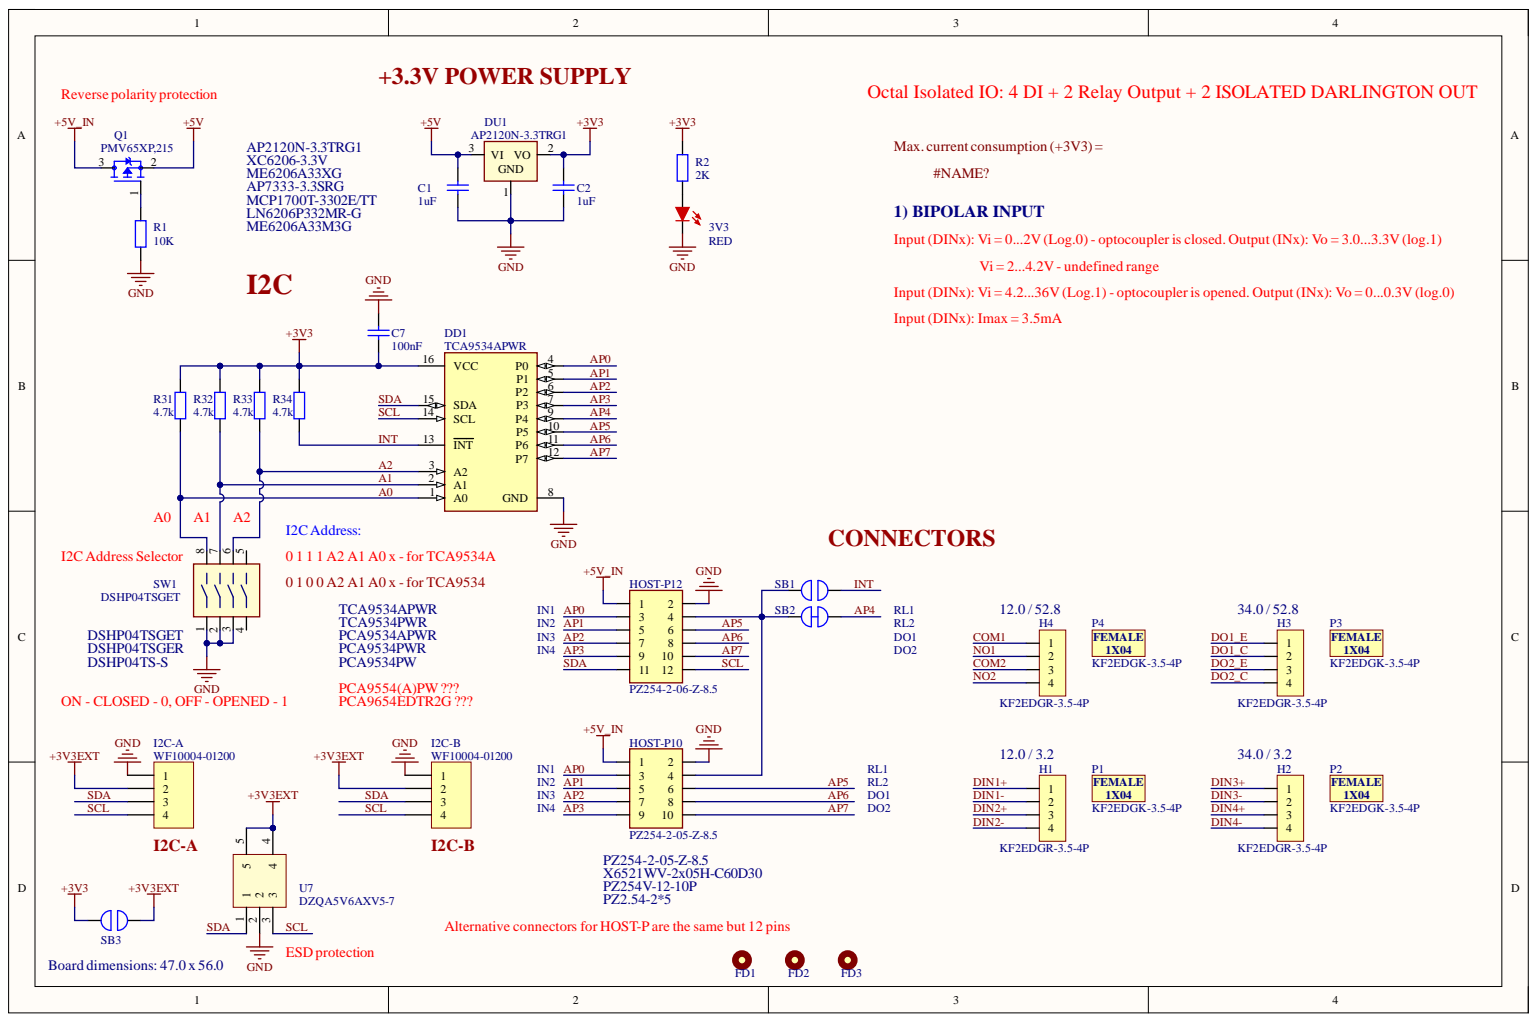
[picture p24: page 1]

Octal Isolated IO: 4 DI + 2 Relay Output + 2 ISOLATED DARLINGTON OUT

Input (DINx): Vi = 0...2V (Log.0) - optocoupler is closed. Output (INx): Vo = 3.0...3.3V (log.1) Vi = 2...4.2V - undefined range

Input (DINx): Vi = 4.2...36V (Log.1) - optocoupler is opened. Output (INx): Vo = 0...0.3V (log.0)

ON - CLOSED - 0, OFF - OPENED - 1

Alternative connectors for HOST-P are the same but 12 pins

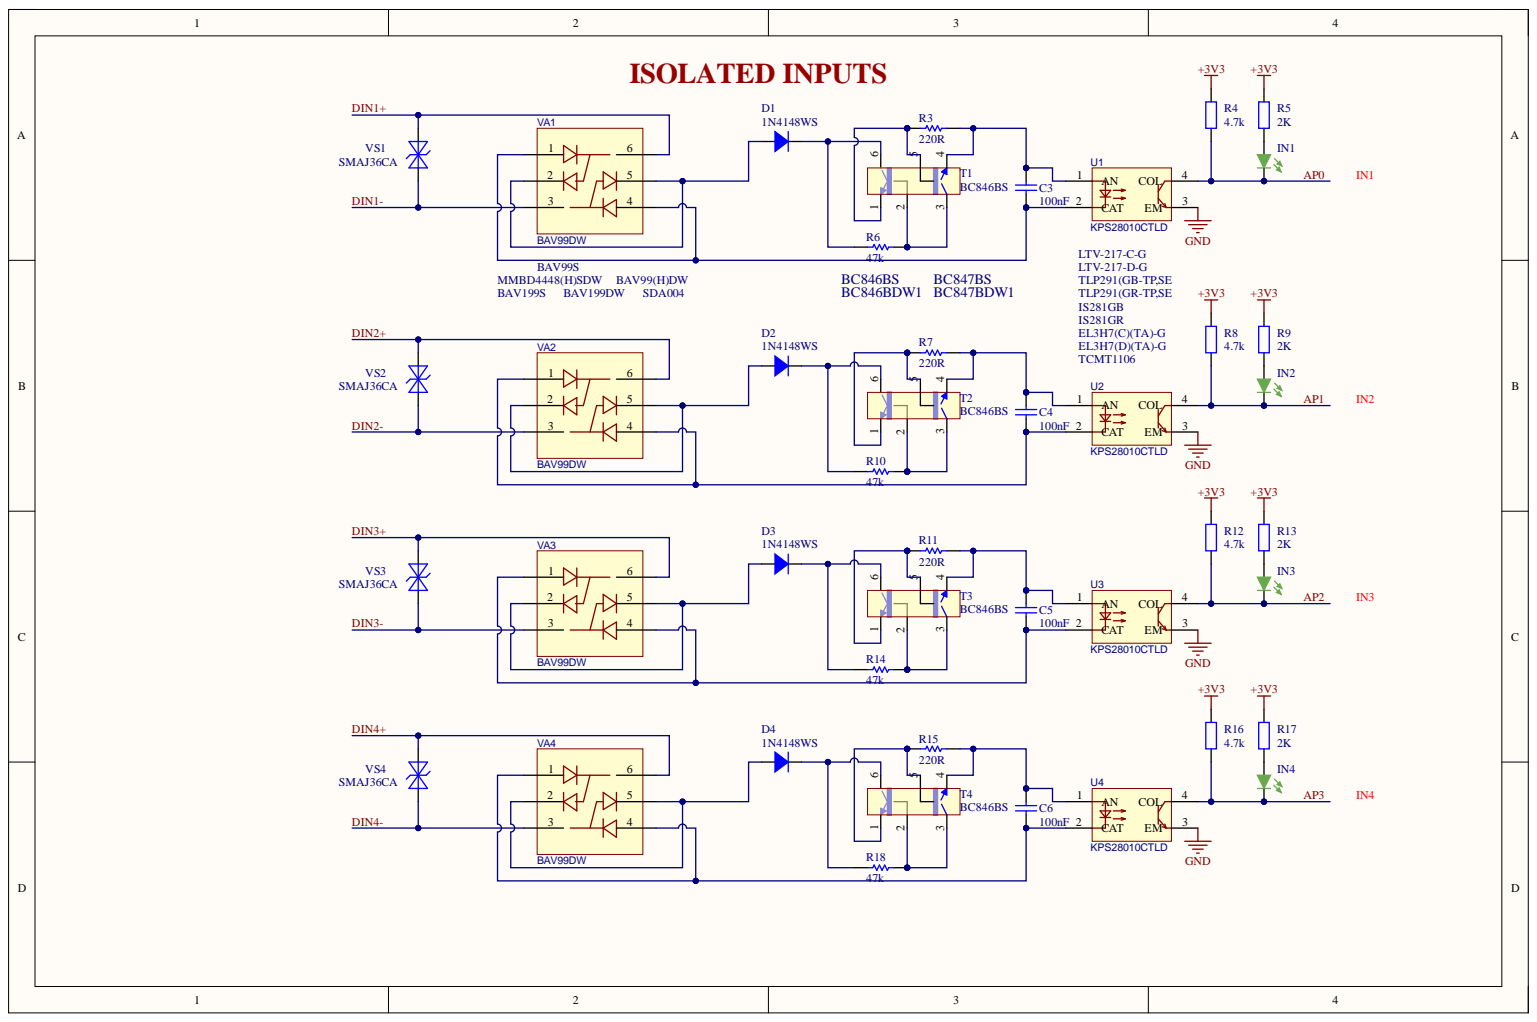
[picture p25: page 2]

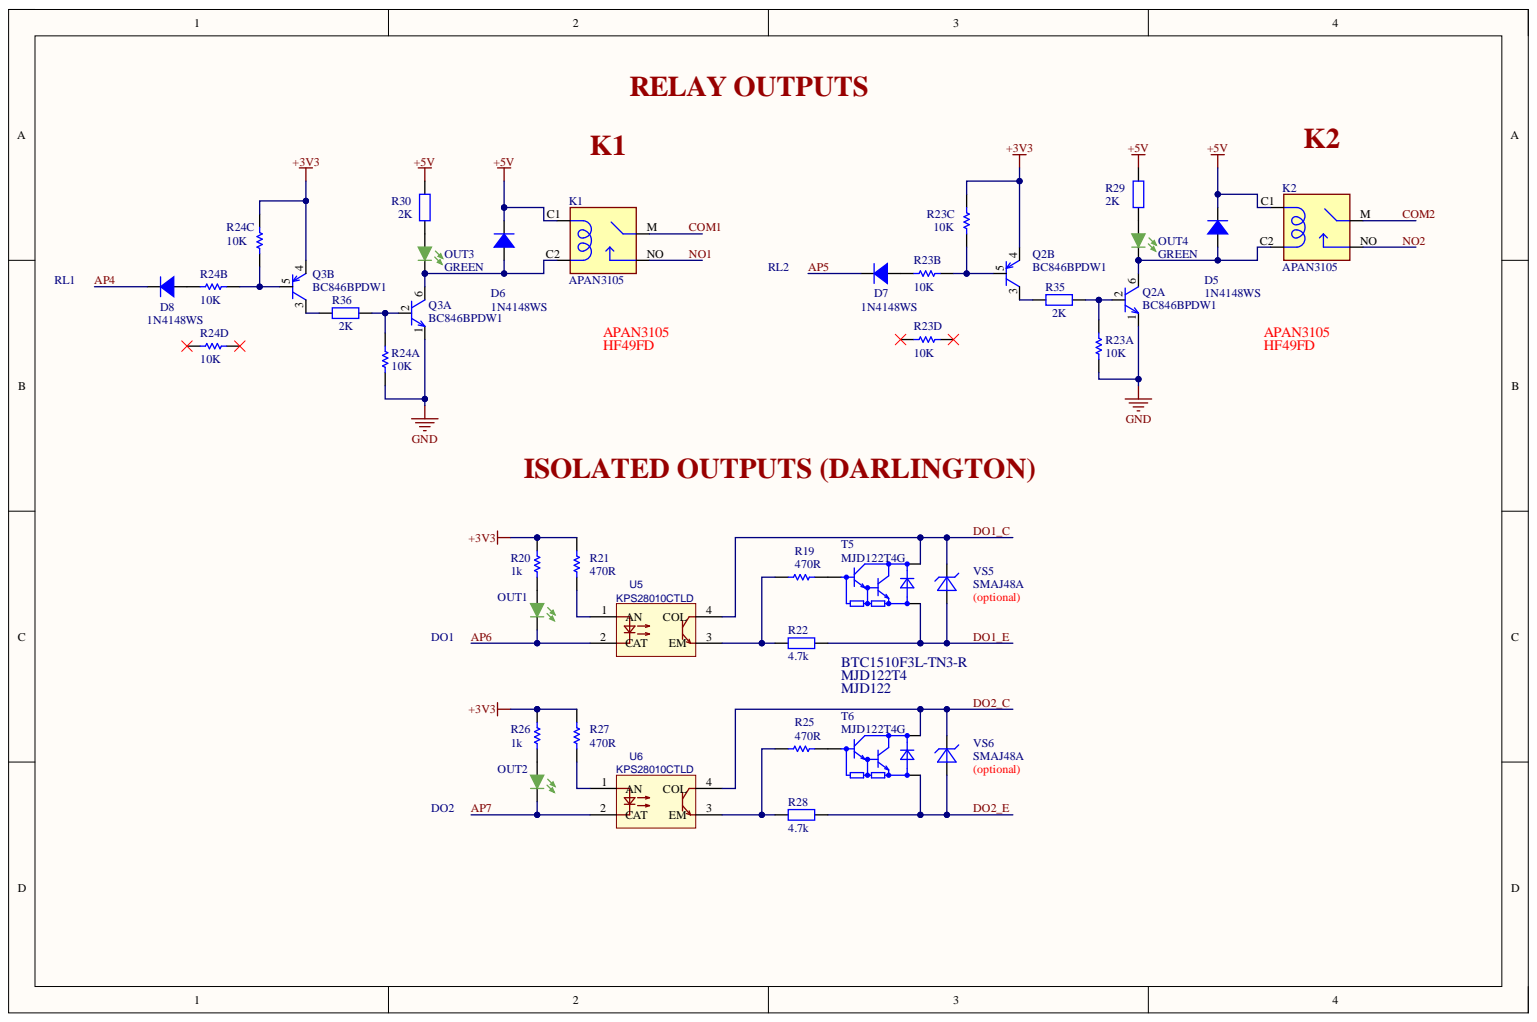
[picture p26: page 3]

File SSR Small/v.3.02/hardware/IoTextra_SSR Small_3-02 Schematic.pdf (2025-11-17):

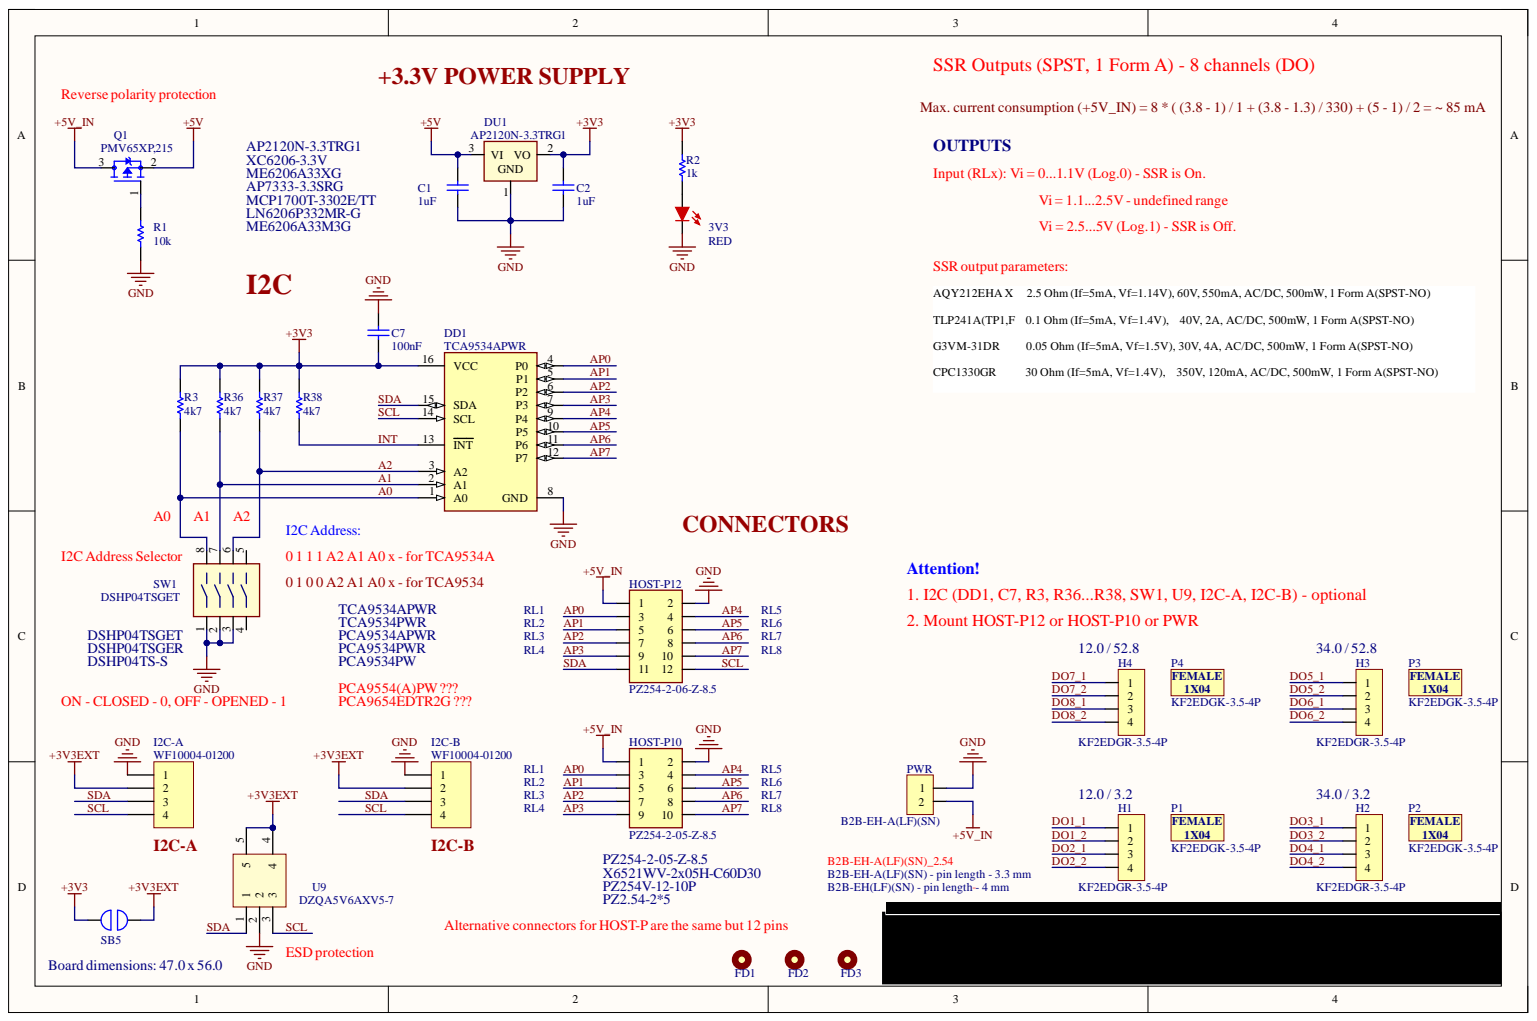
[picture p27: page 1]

SSR Outputs (SPST, 1 Form A) - 8 channels (DO)

Max. current consumption (+5V_IN) = 8 * ( (3.8 - 1) / 1 + (3.8 - 1.3) / 330) + (5 - 1) / 2 = ~ 85 mA

Input (RLx): Vi = 0...1.1V (Log.0) - SSR is On. Vi = 2.5...5V (Log.1) - SSR is Off.

TLP241A(TP1,F 0.1 Ohm (If=5mA, Vf=1.4V), 40V, 2A, AC/DC, 500mW, 1 Form A(SPST-NO)

2. Mount HOST-P12 or HOST-P10 or PWR

ON - CLOSED - 0, OFF - OPENED - 1

B2B-EH-A(LF)(SN) - pin length - 3.3 mm
B2B-EH(LF)(SN) - pin length - 4 mm

Alternative connectors for HOST-P are the same but 12 pins

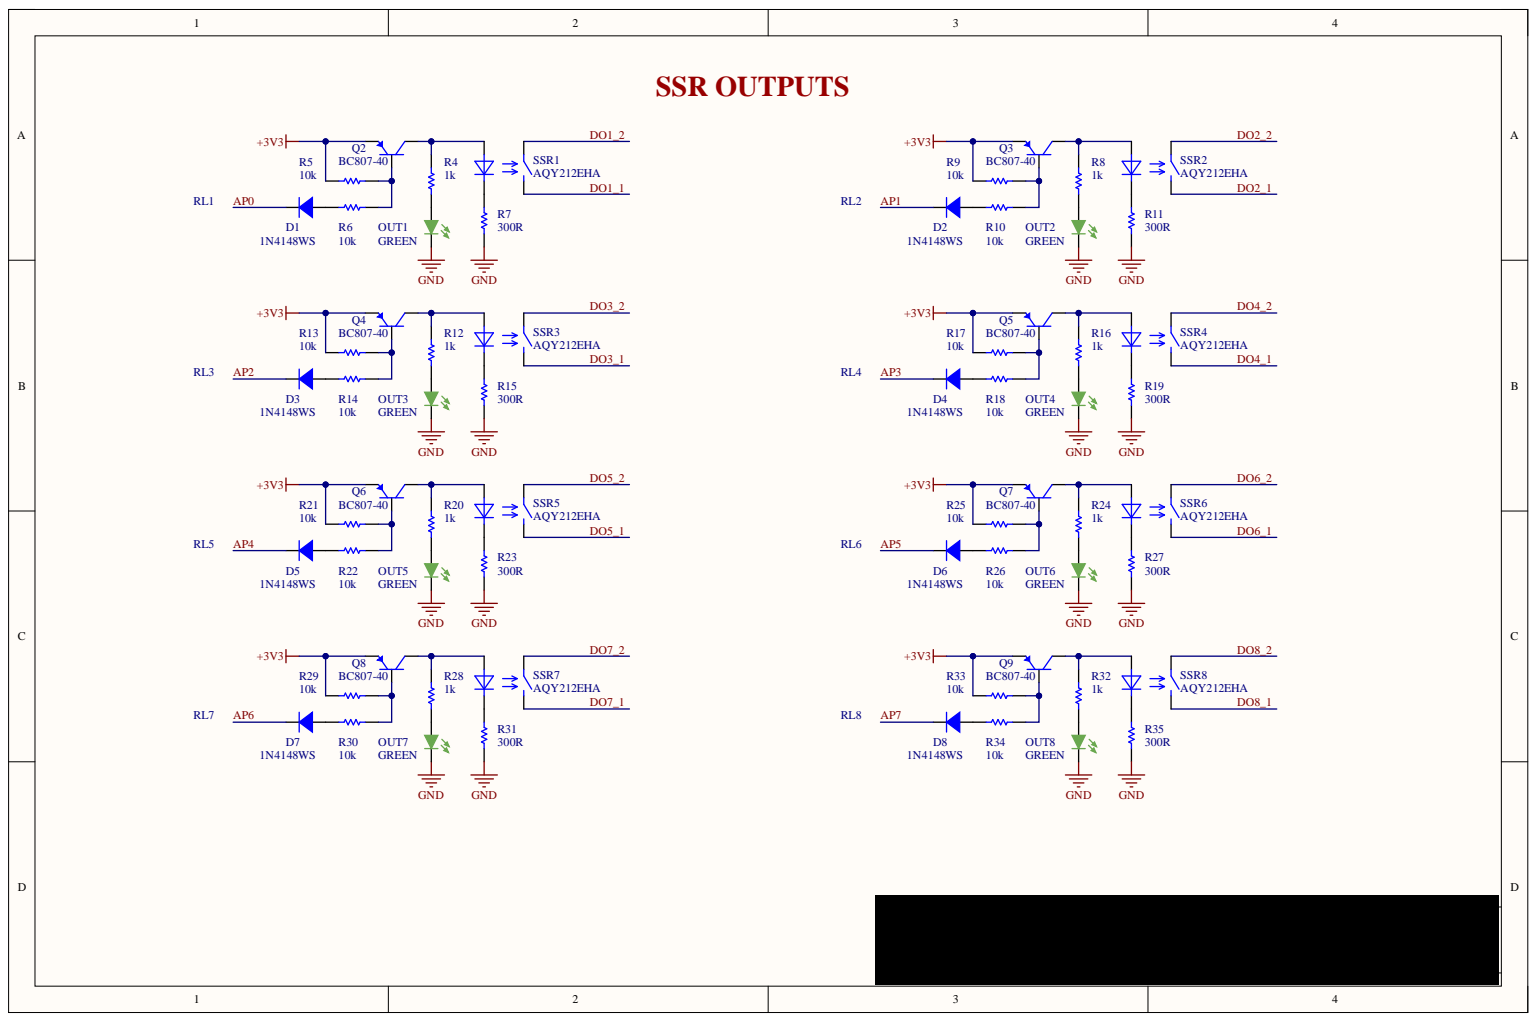
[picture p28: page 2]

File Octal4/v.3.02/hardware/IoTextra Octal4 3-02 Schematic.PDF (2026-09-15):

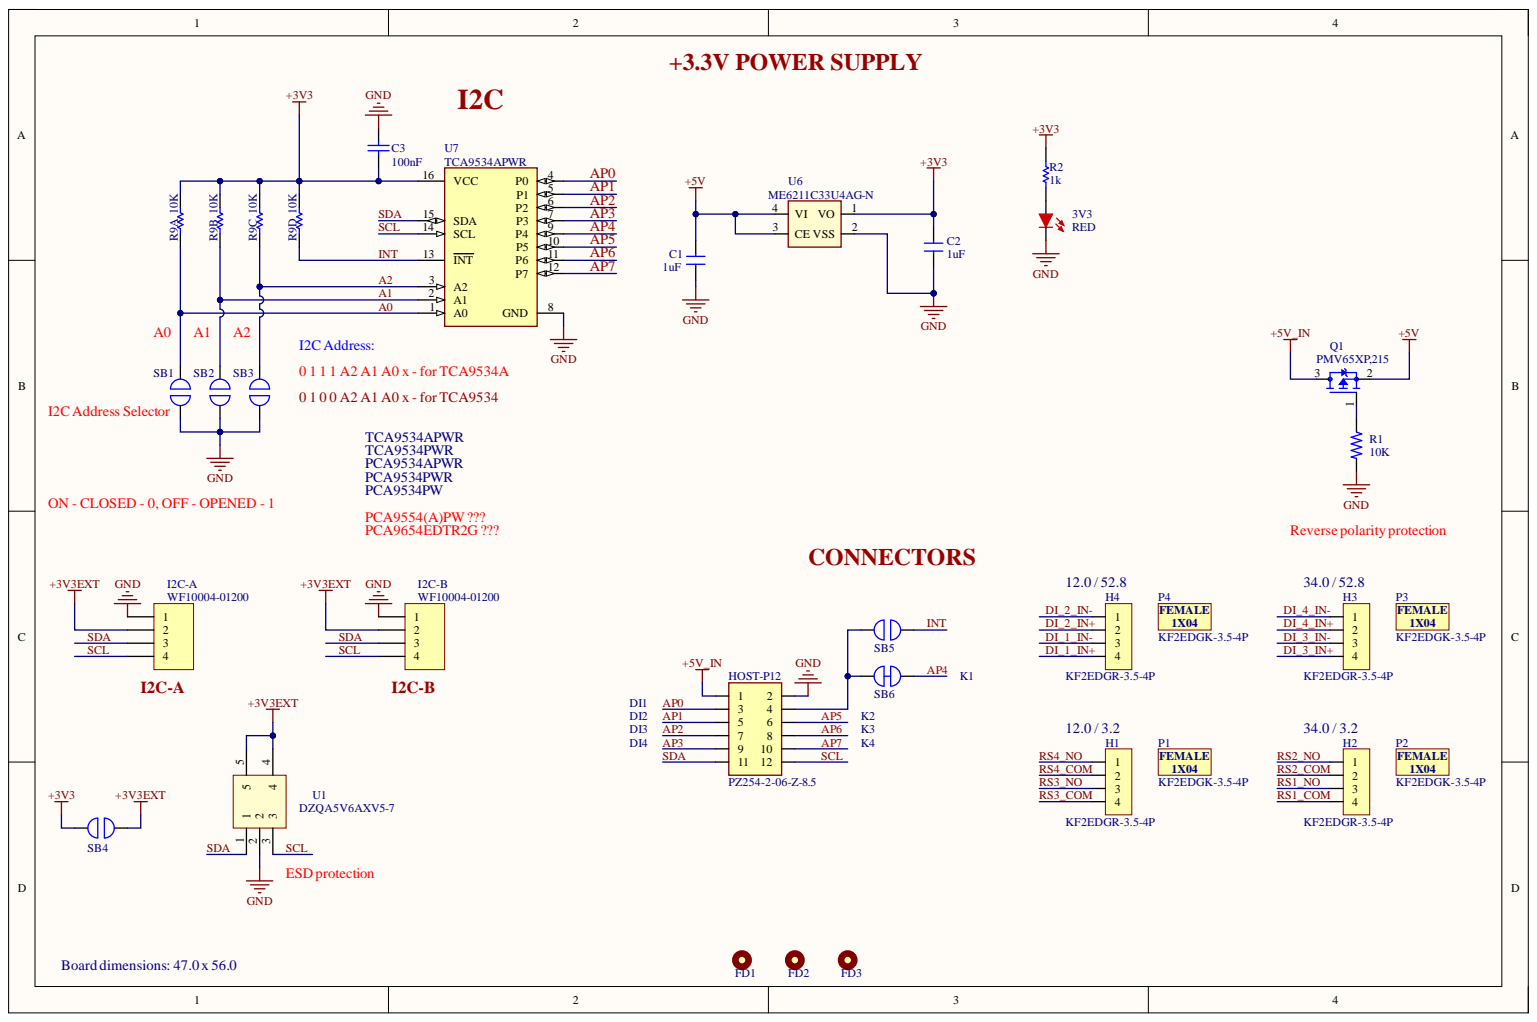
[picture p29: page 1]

ON - CLOSED - 0, OFF - OPENED - 1

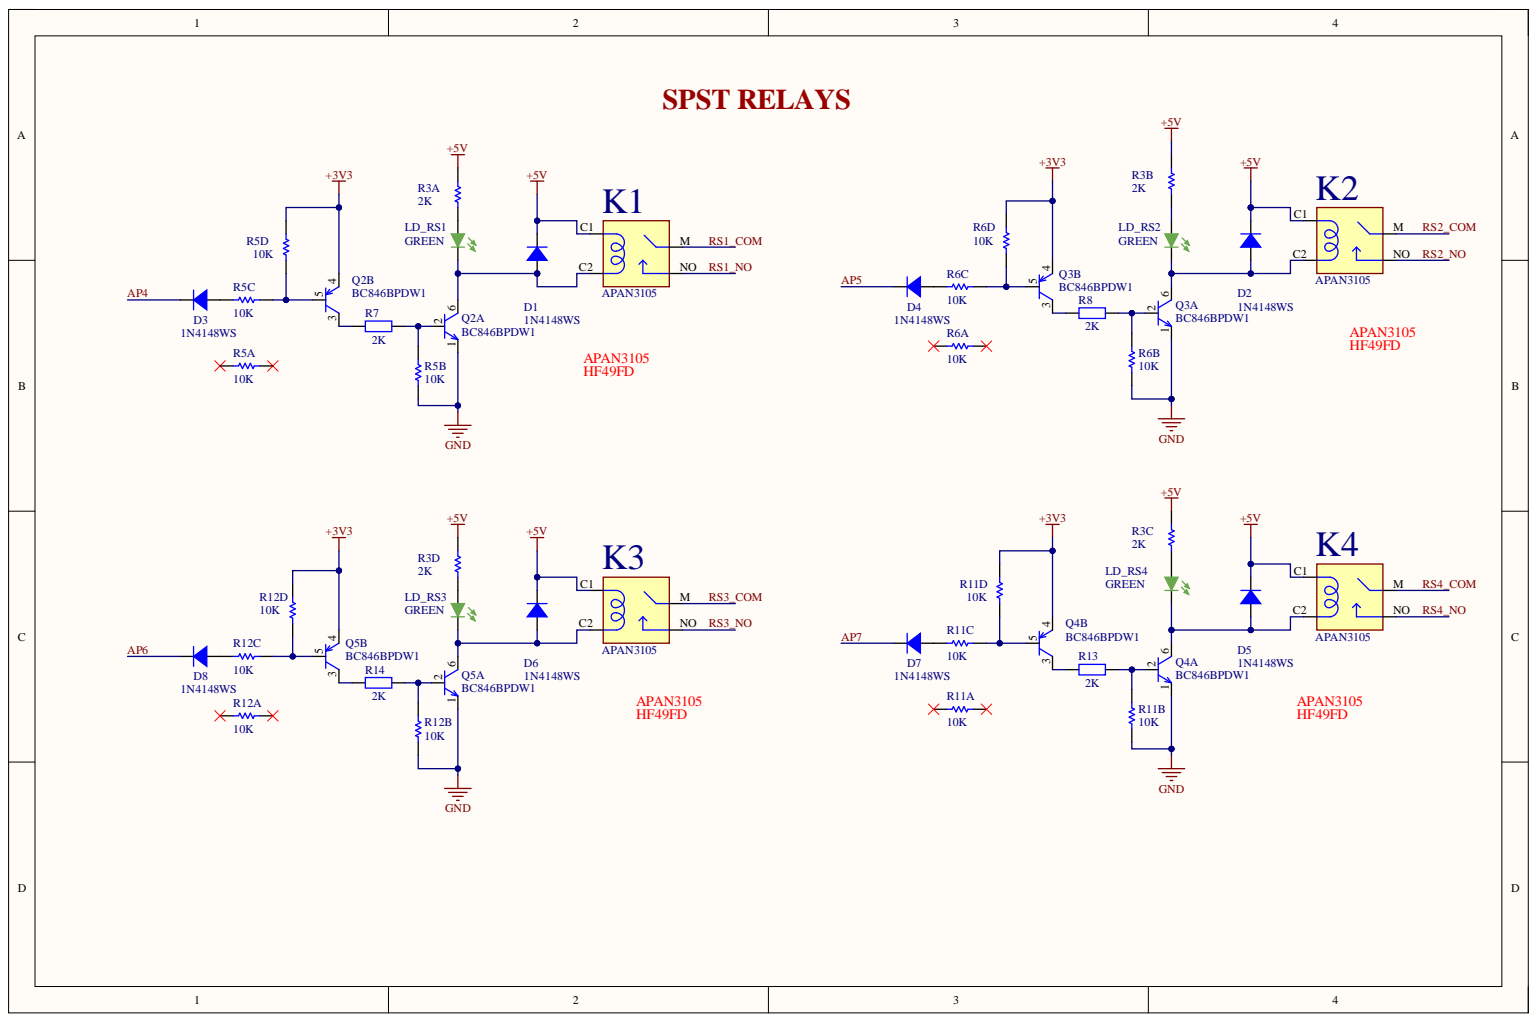
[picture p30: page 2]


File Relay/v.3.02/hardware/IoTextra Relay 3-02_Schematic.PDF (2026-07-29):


ON - CLOSED - 0, OFF - OPENED - 1



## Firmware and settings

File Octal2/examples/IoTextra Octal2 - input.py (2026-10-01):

"""
IoTextra Octal2 - digital inputs, MicroPython example (GPIO mode)
Host: IoTsmart RP2040 (Waveshare RP2040-Tiny)

Reads 4 isolated digital inputs IN1-IN4 via AP0-AP3 on the HOST-P connector.
(Outputs DO1-DO4 are on AP4-AP7, see "IoTextra Octal2 - output.py".)

Signal polarity (IoTextra Octal2 datasheet Rev.3-02):
  input 4...36 V -> AP line reads 0 (ACTIVE)
  input 0...2 V  -> AP line reads 1 (INACTIVE)
"""
from machine import Pin
import time

# IN1..IN4 = AP0..AP3 -> RP2040 GPIO (IoTsmart RP2040 pinout, rev 1-02)
GPIO_PINS = [12, 11, 10, 9]

inputs = [Pin(p, Pin.IN) for p in GPIO_PINS]


def is_active(pin):
    """True when voltage is present on the input (active-low line)."""
    return pin.value() == 0


print("IoTextra Octal2 input monitor. Press Ctrl+C to stop.")

while True:
    print("-" * 36)
    for ch, pin in enumerate(inputs, start=1):
        raw = pin.value()
        state = "ACTIVE   (voltage present)" if is_active(pin) else "inactive (no voltage)"
        print("IN{} (GP{}): raw={} -> {}".format(ch, GPIO_PINS[ch - 1], raw, state))
    time.sleep(1)

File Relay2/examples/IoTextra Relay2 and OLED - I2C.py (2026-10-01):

"""
IoTextra Relay2 over I2C (TCA9534) with SSD1306 OLED status - MicroPython

Hardware
  Base board : IoTbase PICO or IoTbase NANO
  MCU        : ESP32-S3 or RP2040 (detected automatically from sys.platform)
  Module     : IoTextra Relay2 (relays K1-K4 on expander pins P0-P3)
               Also works with IoTextra Combo (relays K1-K2 on P0-P1):
               set RELAY_BITS = (0, 1)
  Display    : SSD1306 128x32 OLED on the same I2C bus (optional)

What it does
  Switches the relays one by one through the TCA9534 I/O expander and shows
  the state of every relay on the OLED and in the console. If no OLED is
  found, the relay cycle still runs with console output only.

Relay polarity (IoTextra Relay2 datasheet)
  Expander pin = 1 -> relay OFF
  Expander pin = 0 -> relay ON
  The output register is written to all-ones BEFORE the pins are switched to
  outputs, so no relay clicks on during initialisation.

TCA9534 address
  Set by the module jumpers / DIP switch, NOT by the MCU type:
    TCA9534  : 0x20...0x27 (module default 0x27)
    TCA9534A : 0x38...0x3F (module default 0x3F)
  With TCA_ADDR = None the address is found by scanning the bus. 0x3C/0x3D are
  skipped during the scan because they are used by the SSD1306 OLED.

Required file on the board: ssd1306.py (standard MicroPython SSD1306 driver),
only if the OLED is used.
"""
from machine import I2C, Pin
import sys
import time

# ----------------------------------------------------------------- settings
BOARD = "pico"              # "pico" -> IoTbase PICO, "nano" -> IoTbase NANO
RELAY_BITS = (0, 1, 2, 3)   # IoTextra Relay2: (0, 1, 2, 3)   IoTextra Combo: (0, 1)
TCA_ADDR = None             # None = auto-detect, or e.g. 0x27 / 0x3F
OLED_ADDR = 0x3C
ON_TIME_S = 1.0             # how long each relay stays ON
OFF_TIME_S = 0.5            # pause after switching a relay OFF

# I2C pins of the HOST connector per base board and MCU
I2C_PINS = {
    ("pico", "rp2"):   {"sda": 20, "scl": 21},
    ("pico", "esp32"): {"sda": 4,  "scl": 5},
    ("nano", "rp2"):   {"sda": 12, "scl": 13},
    ("nano", "esp32"): {"sda": 11, "scl": 12},
}
I2C_FREQ = 400000


# ----------------------------------------------------------------- TCA9534
class TCA9534:
    """Minimal TCA9534 / TCA9534A driver for output use."""

    REG_INPUT = 0x00
    REG_OUTPUT = 0x01
    REG_CONFIG = 0x03       # bit = 1 -> input, bit = 0 -> output

    def __init__(self, i2c, address, output_bits):
        self.i2c = i2c
        self.address = address
        self.out_mask = 0
        for bit in output_bits:
            self.out_mask |= 1 << bit
        # Shadow copy of the output register: all ones = all relays OFF
        self.state = 0xFF
        # 1) set output latches HIGH first, 2) only then enable the outputs
        self._write(self.REG_OUTPUT, self.state)
        self._write(self.REG_CONFIG, 0xFF & ~self.out_mask)

    def _write(self, reg, value):
        self.i2c.writeto_mem(self.address, reg, bytes([value]))

    def write_bit(self, bit, level):
        """Set one expander pin to 0 or 1 (read-modify-write on the shadow)."""
        if level:
            self.state |= 1 << bit
        else:
            self.state &= ~(1 << bit)
        self._write(self.REG_OUTPUT, self.state)

    def set_all(self, level):
        """Set all configured output pins to the same level."""
        if level:
            self.state |= self.out_mask
        else:
            self.state &= ~self.out_mask
        self._write(self.REG_OUTPUT, self.state)


# ----------------------------------------------------------------- helpers
def find_tca9534(addresses):
    """Return the first expander address found on the bus (defaults first)."""
    candidates = [0x27, 0x3F]
    candidates += [a for a in range(0x20, 0x28) if a not in candidates]
    candidates += [a for a in range(0x38, 0x40)
                   if a not in candidates and a not in (0x3C, 0x3D)]
    for addr in candidates:
        if addr in addresses:
            return addr
    return None


def relay_on(tca, bit):
    tca.write_bit(bit, 0)       # active-low


def relay_off(tca, bit):
    tca.write_bit(bit, 1)


def relay_states(tca):
    """List of booleans: True = relay ON."""
    return [not (tca.state >> bit) & 1 for bit in RELAY_BITS]


def show_status(oled, tca, message):
    """Print the status line and update the OLED (if present)."""
    states = relay_states(tca)
    line = " ".join("K{}:{}".format(i, "1" if on else "0")
                    for i, on in enumerate(states, start=1))
    print("{:<14} {}".format(message, line))
    if oled is None:
        return
    # 128 px = 16 characters per line, so the OLED gets a compact form,
    # e.g. "K1-K4: 1000" (1 = ON)
    compact = "K1-K{}: {}".format(
        len(states), "".join("1" if on else "0" for on in states))
    oled.fill(0)
    oled.text("TCA9534 0x{:02X}".format(tca.address), 0, 0)
    oled.text(message, 0, 12)
    oled.text(compact, 0, 24)
    oled.show()


# ----------------------------------------------------------------- main
def main():
    chip = sys.platform                     # "rp2" or "esp32"
    pins = I2C_PINS.get((BOARD, chip))
    if pins is None:
        print("No I2C pin map for board '{}' with '{}'".format(BOARD, chip))
        return

    i2c = I2C(0, sda=Pin(pins["sda"]), scl=Pin(pins["scl"]), freq=I2C_FREQ)
    found = i2c.scan()
    print("I2C devices:", [hex(a) for a in found])

    addr = TCA_ADDR if TCA_ADDR is not None else find_tca9534(found)
    if addr is None or addr not in found:
        print("TCA9534 not found - check the module and its address jumpers")
        return
    tca = TCA9534(i2c, addr, RELAY_BITS)
    print("TCA9534 at 0x{:02X}, relays on P{}".format(
        addr, ", P".join(str(b) for b in RELAY_BITS)))

    oled = None
    if OLED_ADDR in found:
        try:
            from ssd1306 import SSD1306_I2C
            oled = SSD1306_I2C(128, 32, i2c, addr=OLED_ADDR)
        except Exception as e:              # driver missing or init error
            print("OLED disabled:", e)
    else:
        print("No OLED at 0x{:02X} - console output only".format(OLED_ADDR))

    show_status(oled, tca, "All OFF")
    print("Relay cycle running. Press Ctrl+C to stop.")
    try:
        while True:
            for k, bit in enumerate(RELAY_BITS, start=1):
                relay_on(tca, bit)
                show_status(oled, tca, "K{} ON".format(k))
                time.sleep(ON_TIME_S)
                relay_off(tca, bit)
                show_status(oled, tca, "K{} OFF".format(k))
                time.sleep(OFF_TIME_S)
    finally:
        tca.set_all(1)                      # every relay OFF on exit
        show_status(oled, tca, "Stopped")


main()

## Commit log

2025-11-22 README Content (Ready To Review)
    Expanded the README to provide detailed information about IoTextra-Digital modules, including features, specifications, wiring diagrams, software support, and ordering options.
2026-08-24 Auto-sync overview for Relay2
2026-08-24 Auto-sync overview for MOSFET2
